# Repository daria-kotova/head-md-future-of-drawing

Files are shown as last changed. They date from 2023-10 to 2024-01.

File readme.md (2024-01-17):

This is my project with Caran d'Ache on the future of drawing, where we have to make a playful AI creative assistant. 

Current name of my assistant is Snailed-it.

Below is the devlog with my day-to-day progress. Enjoy.

# DevLog

## 2024-01-17

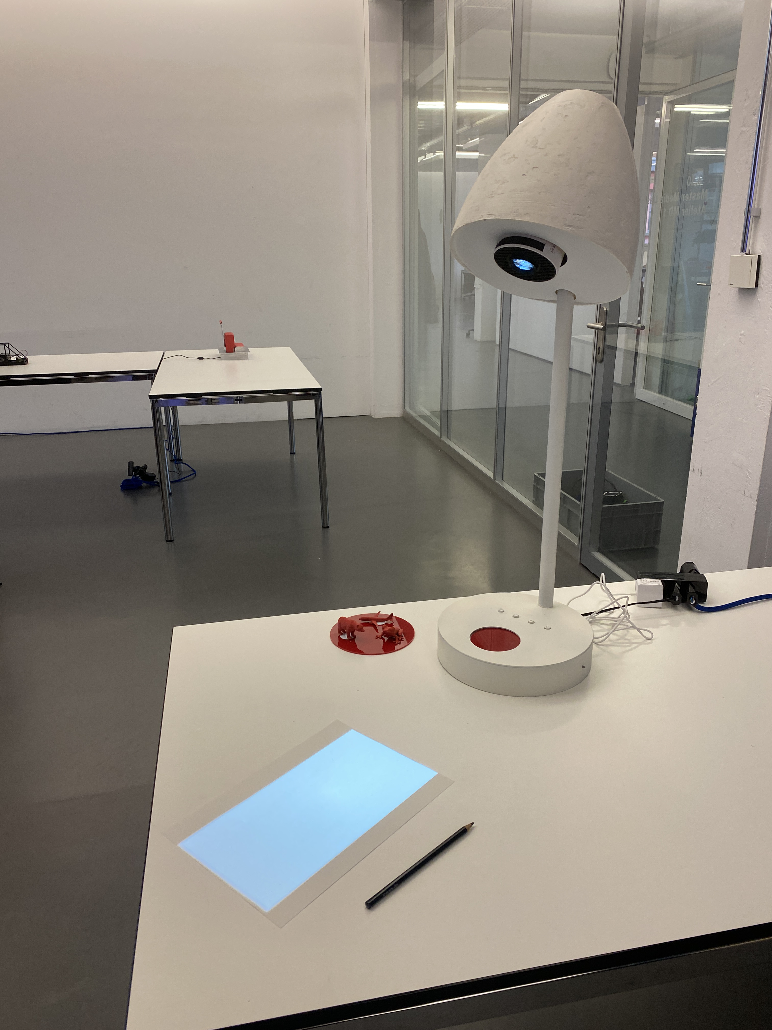
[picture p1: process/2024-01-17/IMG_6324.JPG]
exp


Murphy's law continues to work, the code that worked last night and this morning did not work during my demo. Had to show images on my iPad, again. Quite dissapointed with this, but at least I know it works and I am satisfied with the final form. Achievemebt unlocked. Product designed.

## 2024-01-16

Spent 6,5 hours figuring out my [code](/electronics/code/) with Vitas. And it worked! For now only two buttons are functional (outline and shading) and the image does not disappear when you remove an NFC tag. But still. Happy. 

However, I had not expected it to take sooo much time. So when I came back to the main building to get all my stuff, it was already locked. Had a mini panick attack. But crisis was averted, Lauren saved me.

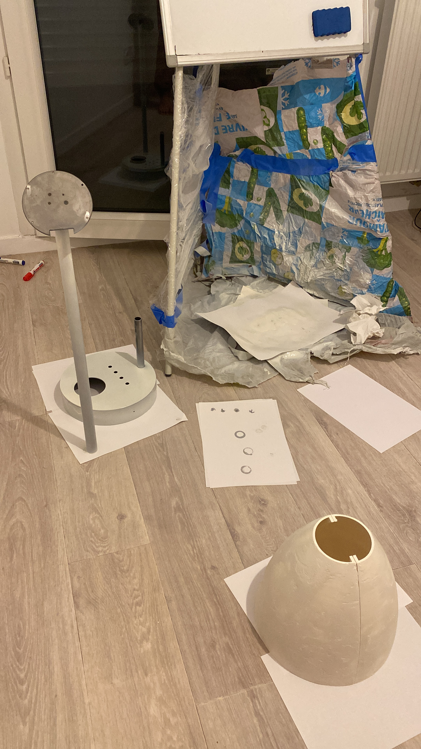
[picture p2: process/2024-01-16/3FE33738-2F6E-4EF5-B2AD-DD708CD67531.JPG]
paint
Painted my parts in white at home. 

## 2024-01-15

After some struggling with Processing I decided to code in Python, even though I had never done it before.

Tutorial for setting up RFID RC522 https://pimylifeup.com/raspberry-pi-rfid-rc522/ 

Stayed up till 1am and managed to write  scripts for reading NFC tags and displaying a related image, as well as ditacting the state of buttons. Chat GPT is trully useless in some cases, it just repeats itself and does not fix my issues.

Prepared my final [pdf](/presentations/240117_HEAD-MD1_Caran-d-Ache_Daria-Kotova-Snailed-it.pdf).

## 2024-01-14

Spent half of the day looking for a micro HDMI cable in the shops around home. It was quite a challenge, taking that it is Sunday. 

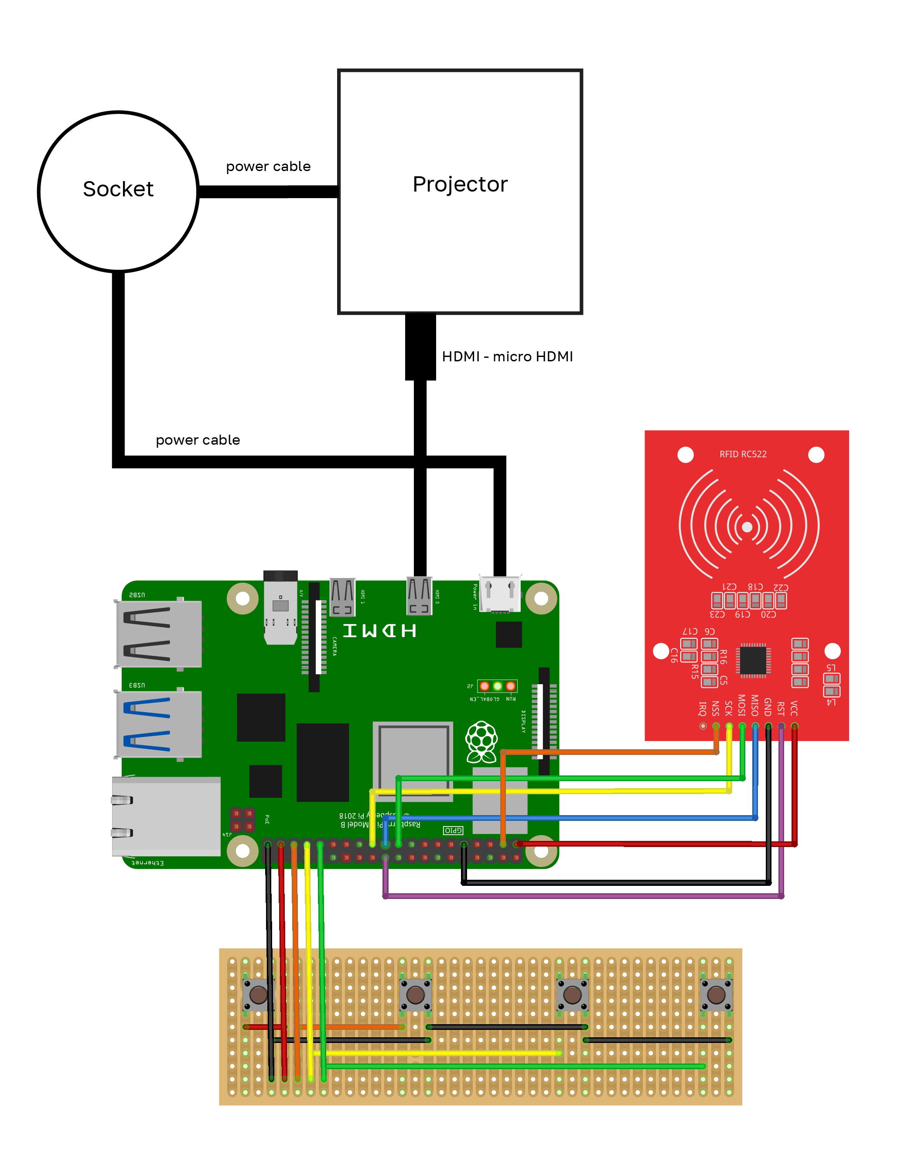
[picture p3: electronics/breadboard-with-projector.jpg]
schematic
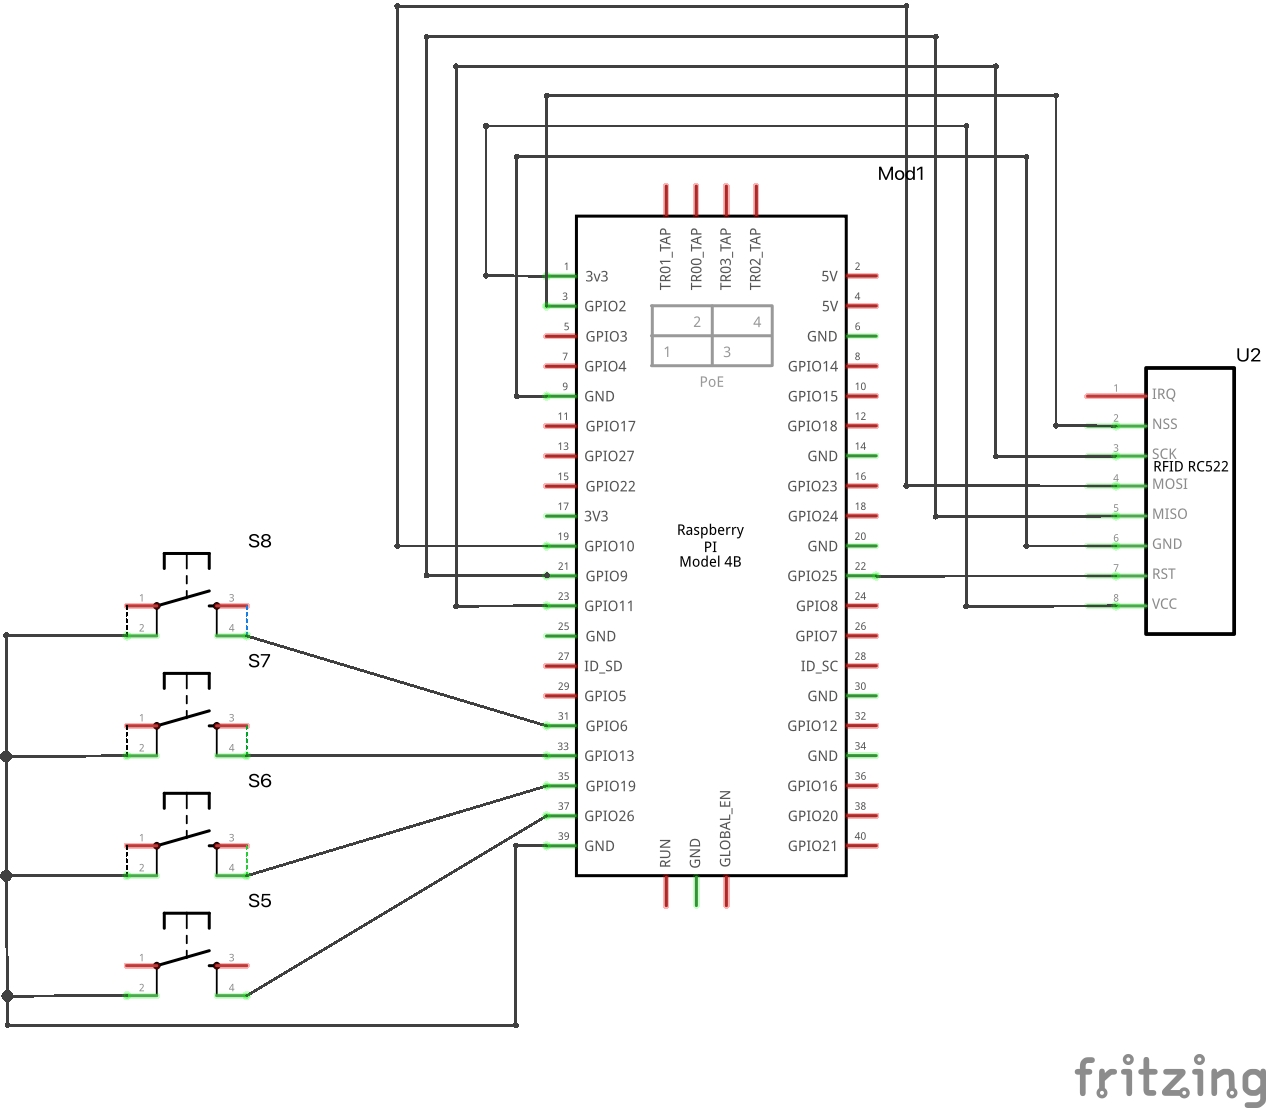
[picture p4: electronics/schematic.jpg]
shematic-1
Prepared my Fritzing schematic  

Well.. Cellotape does not really secure the SD card slot in place, the Pi keeps crushing. Will have to get another Pi from school.

## 2024-01-13

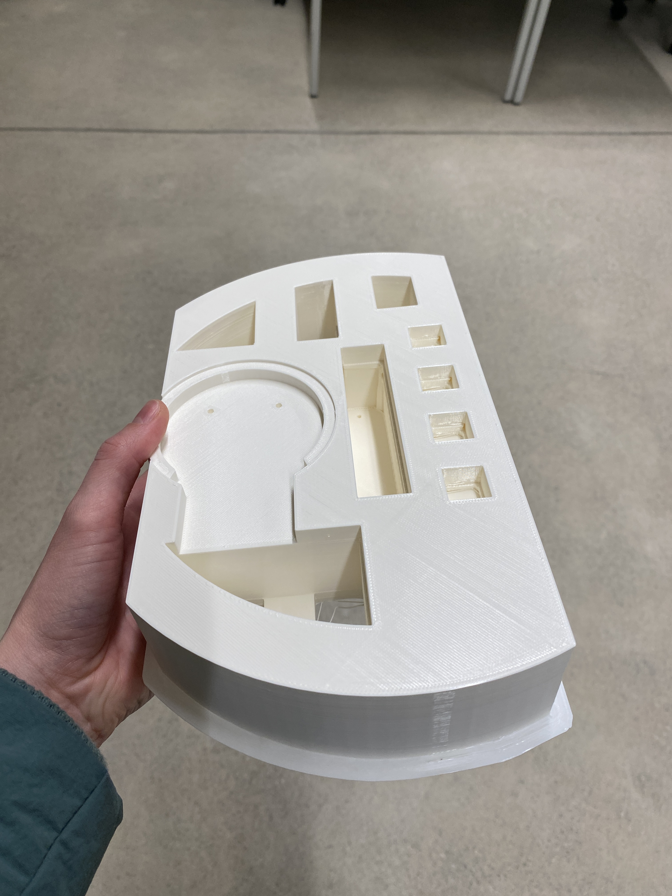
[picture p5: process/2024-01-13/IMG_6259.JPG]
base
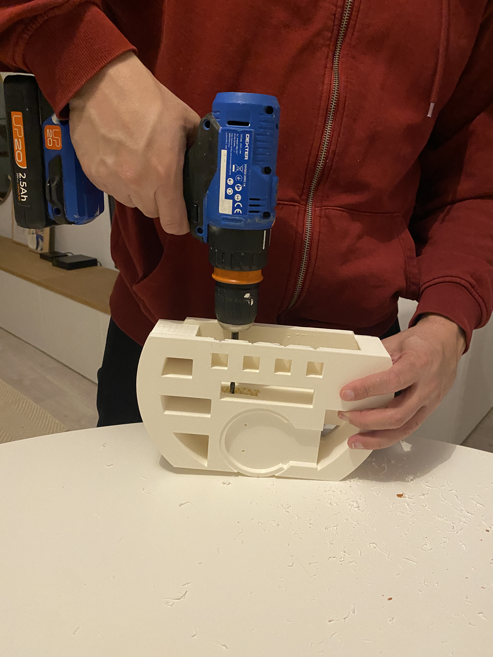
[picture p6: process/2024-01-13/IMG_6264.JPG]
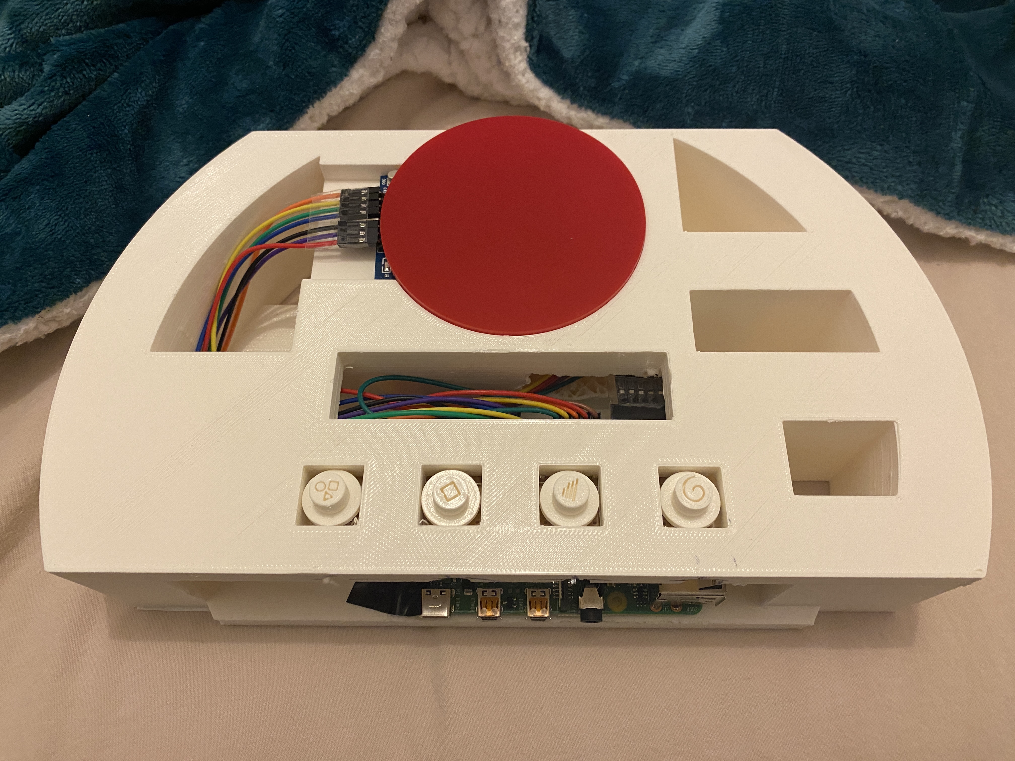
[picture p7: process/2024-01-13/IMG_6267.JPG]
Went to school to get my 3D base for electronics  Spent 2-3 hours cleaning it from all the supports, only to find out that I had made a mistake in modelling. Even two. I forgot to consider how I am going to put the strip board with buttons inside. Also, need some extra space for cables. Had to fix it with a drill.  But now everything seems to fit inside 

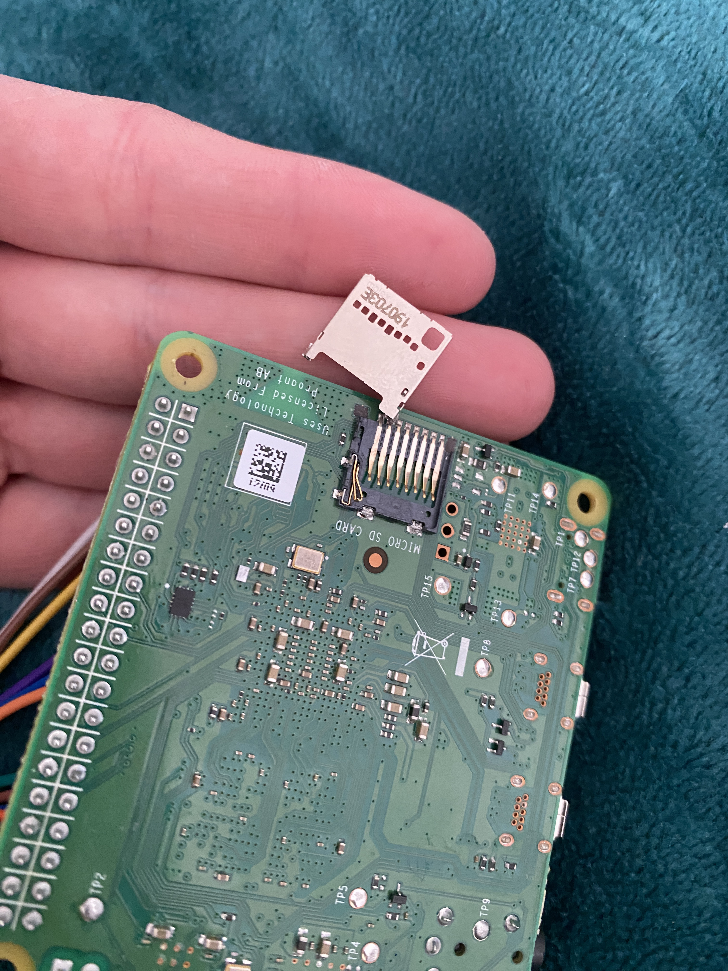
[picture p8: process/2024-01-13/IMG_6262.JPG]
slot
I somehow managed to broke the slot for SD card on my raspberry pi... 

Wanted to focus on my code, buuut... I left my micro HDMI cable at school..

## 2024-01-12

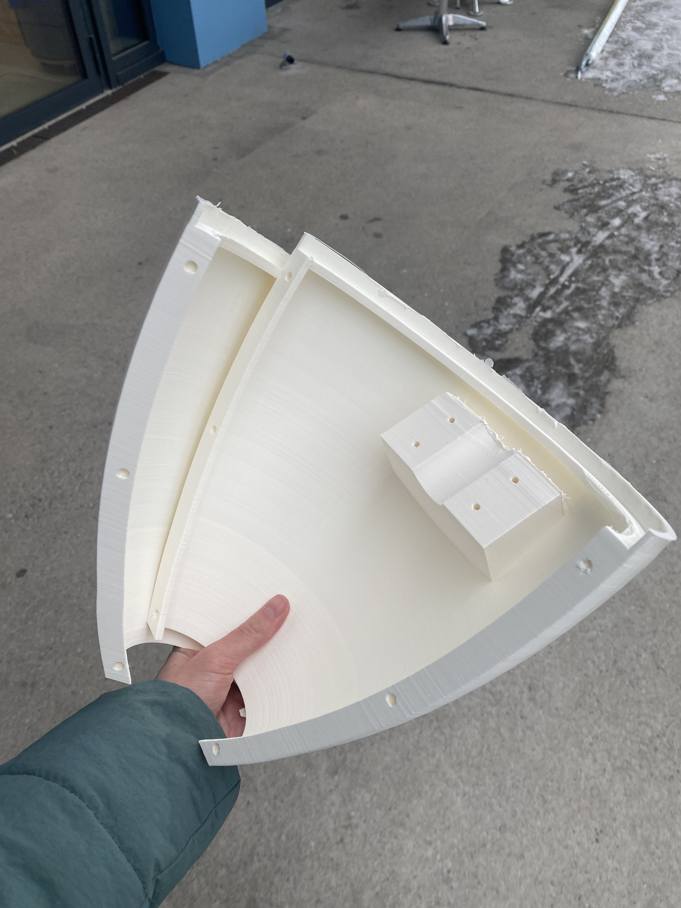
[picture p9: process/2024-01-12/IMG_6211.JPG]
parts
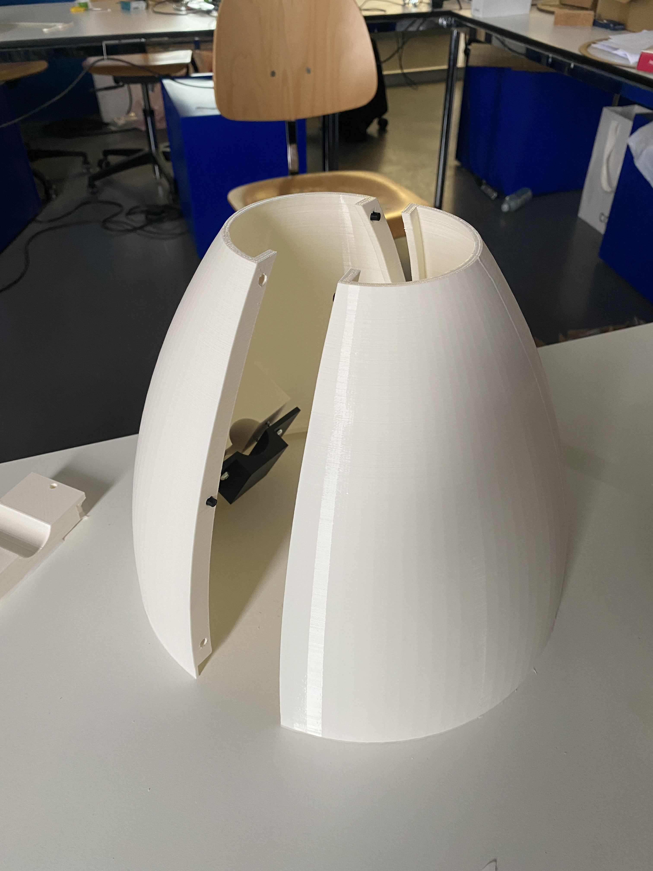
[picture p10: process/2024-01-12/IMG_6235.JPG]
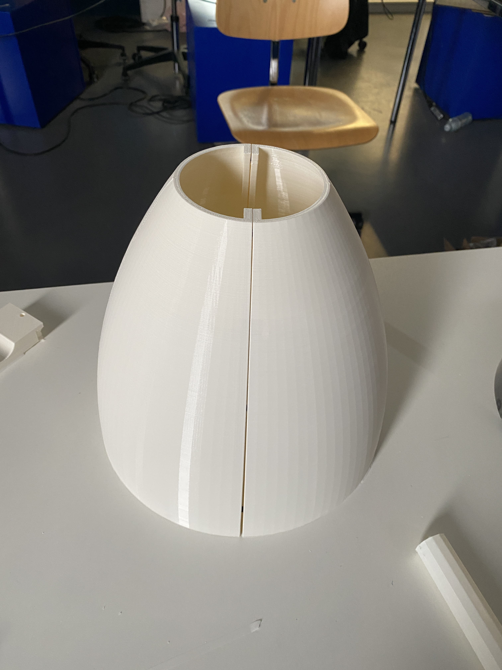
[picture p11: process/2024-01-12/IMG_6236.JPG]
Got my two big 3D printed top parts and some parts for fixations.    They took 11 and 14 hours to print. The 3D base is going to take 18 hours to print lol. The 3D printing industry needs to work more on their speed :/

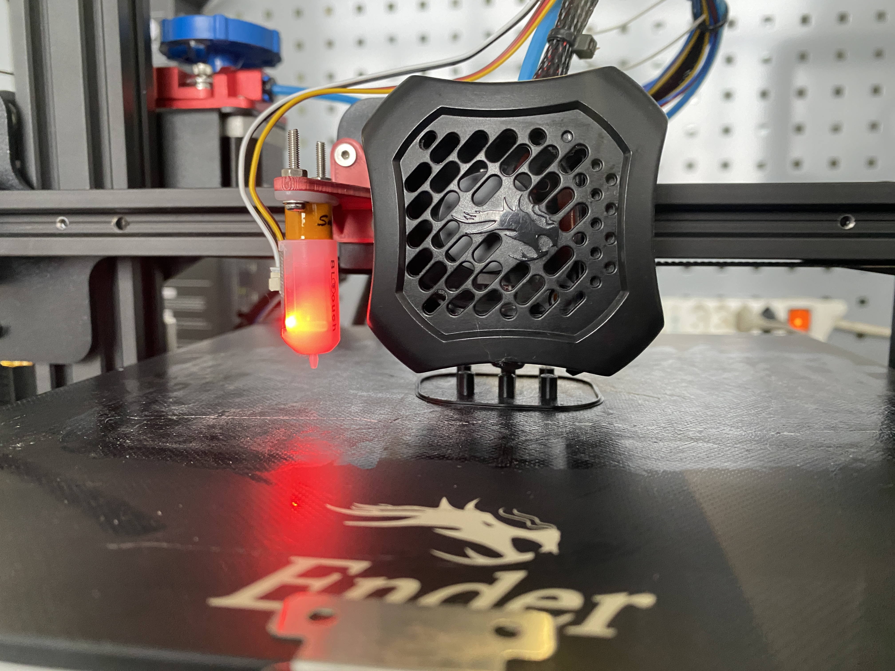
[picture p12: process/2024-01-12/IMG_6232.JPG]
The technique for connecting parts, that Fred told me about, when you make holes in both parts and then print connecting sticks separately, did not work. I completely mismatched the measurings, had to reprint the sticks twice myself 

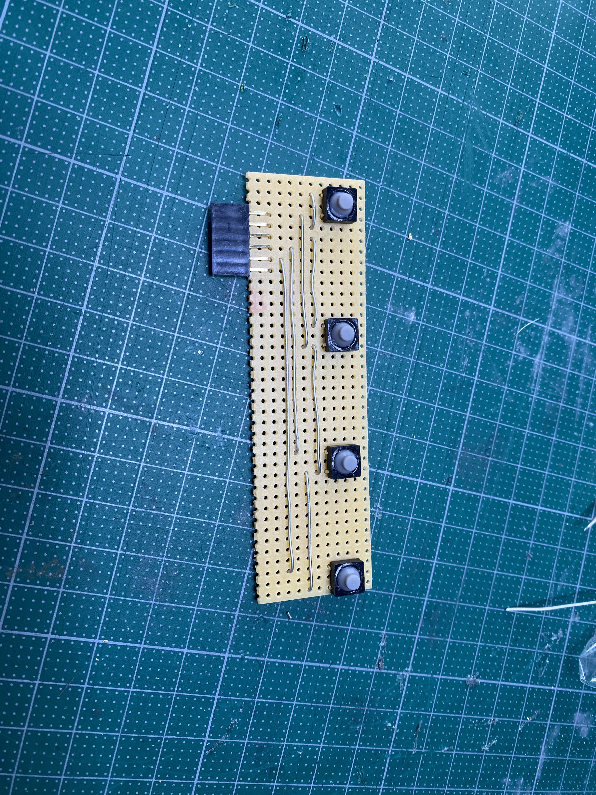
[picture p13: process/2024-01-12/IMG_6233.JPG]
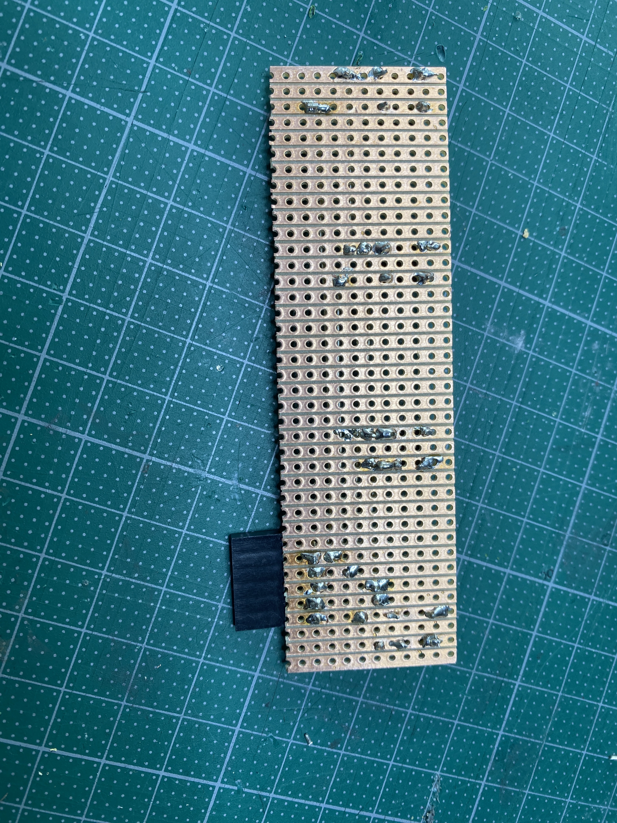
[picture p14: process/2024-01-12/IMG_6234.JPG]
Soldered my buttons. I think I am getting a hang of it.  

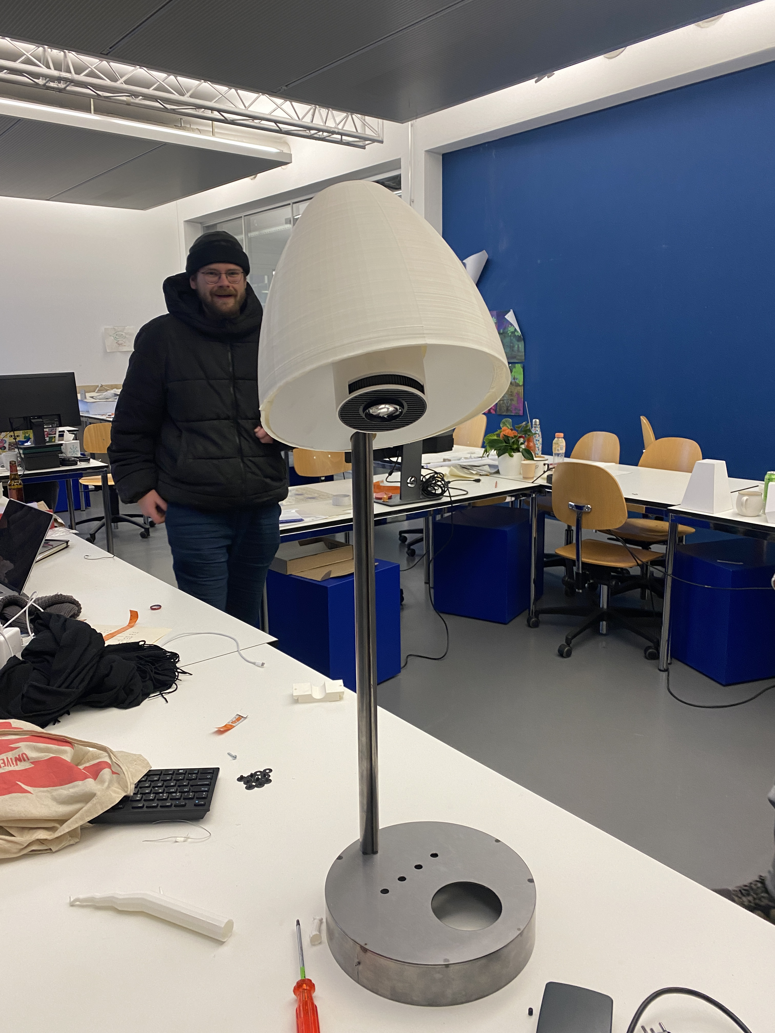
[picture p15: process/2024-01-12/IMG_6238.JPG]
form
Overall, the object is starting to take its from 

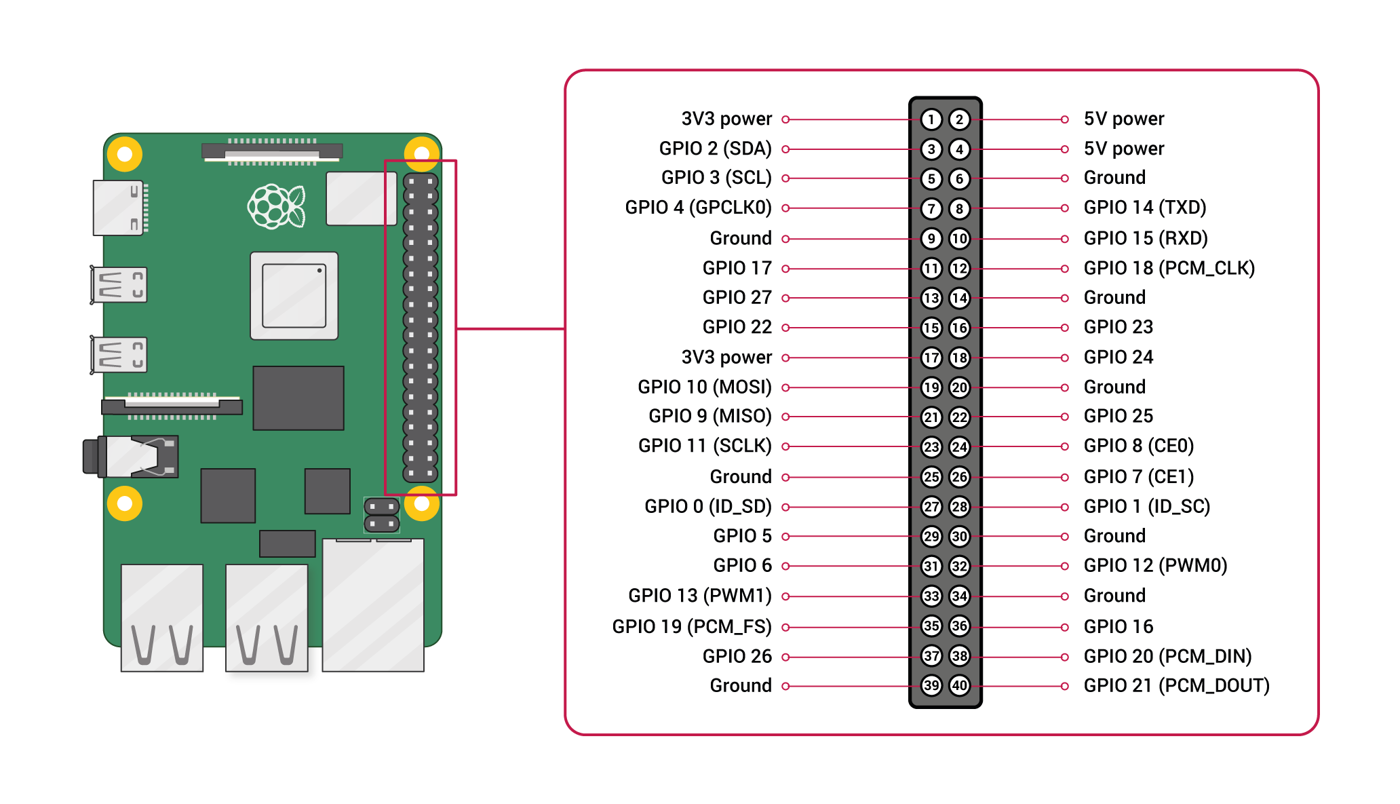
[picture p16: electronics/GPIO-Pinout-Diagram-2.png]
My Bible for the next several days 

## 2024-01-11

Got laser and zonde (?) cuts. Finally finished my battle with the 3D base. 

## 2024-01-10

Figuring out the electronics and 3D base. Prepared documents for laser cutting (fixation disks, plate, diffusor).

## 2024-01-09

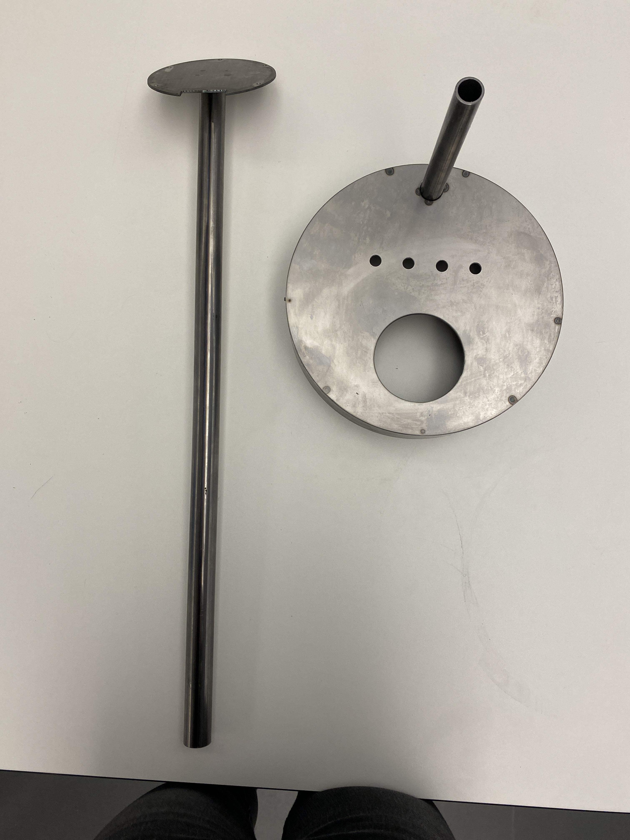
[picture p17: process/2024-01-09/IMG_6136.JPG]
metal
Went to metal workshop. We managed to finish in 3 hours. When I say we, I mean Xavier, I was just giving instructions and following him everywhere lol. Satisfied with the result.  However, at the end we realized that the tubes are to narrow and the projector power cable does not pass. Will have to cut it and get a new prise that can be opened. Ooops.

## 2024-01-08

Trying to finalize my 3D model because tomorrow I will go to the metal workshop. Still struggling a lot with the 3D base, because I fail to imagibe how everything will be positioned.

## 2024-01-10

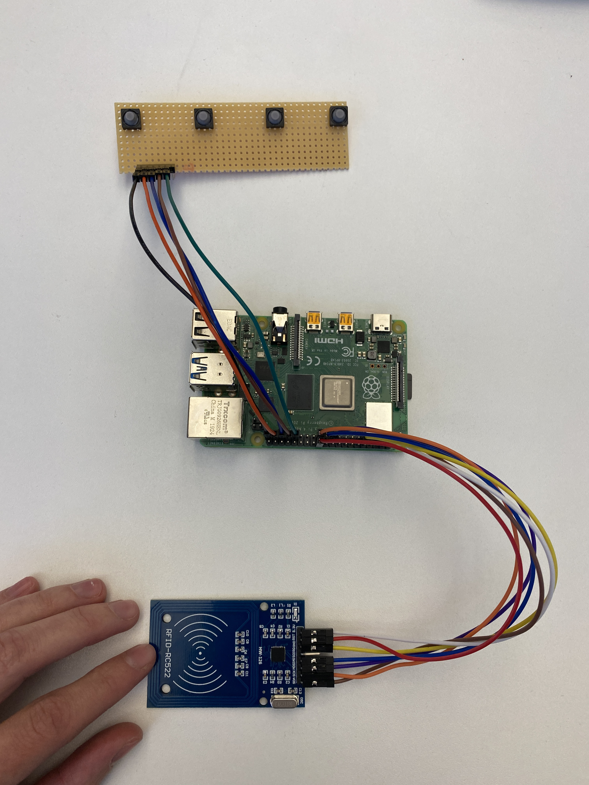
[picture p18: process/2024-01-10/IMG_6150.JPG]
solder
Finally figured out my electronics situation (how every part connects to each other). Gonna solder buttons. 

## 2024-01-04

Chose 5 more input objects (to be limited to 4). Unfortunately no snail :( Ideally, I would have modelled them myself, but seems like a waste of time with my current level of 3D modelling.

- sheep https://www.thingiverse.com/thing:182273/files
- plane https://www.thingiverse.com/thing:182252/files
- penguin https://www.thingiverse.com/thing:182246/files
- bear https://www.thingiverse.com/thing:182072/files
- frog https://www.thingiverse.com/thing:18479/files

## 2023-12-23

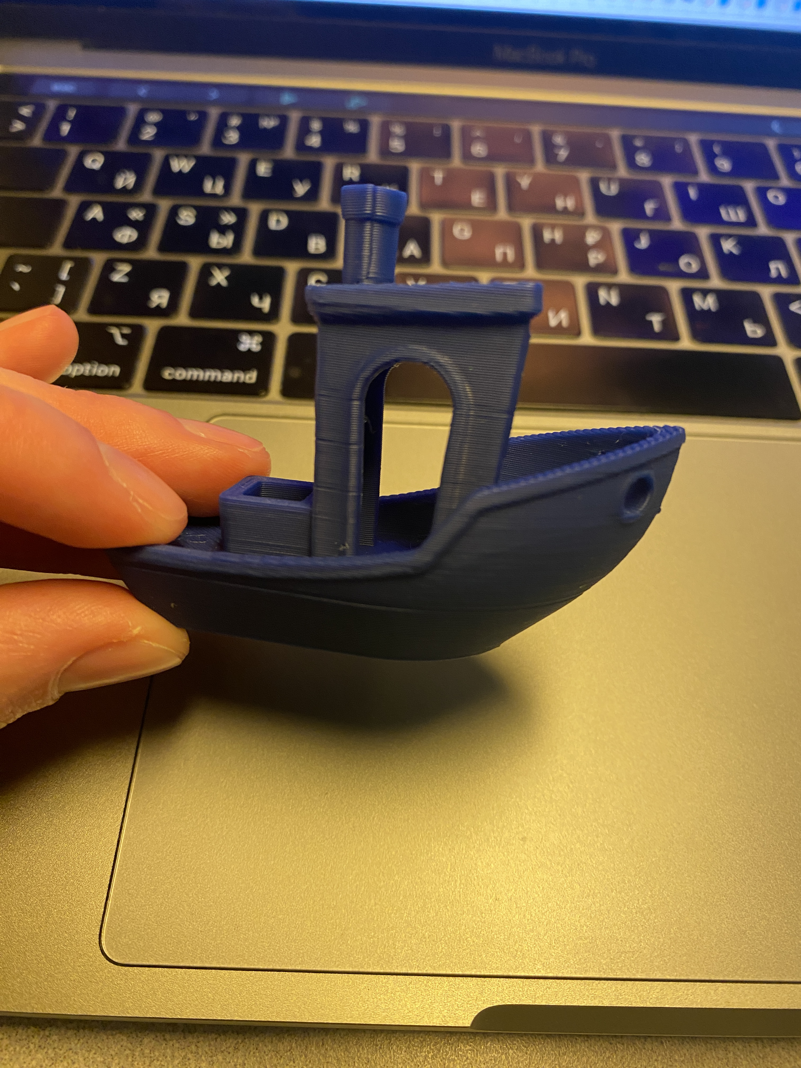
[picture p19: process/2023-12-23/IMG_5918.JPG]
boat
Jasmine got me a 3D printed boat as another input object for my project.  Now I am thinking that I should 3D print all of my input objects, so that they are all in one style. Deffinitely one of the objects will be a snail (DAH).

## 2023-12-21

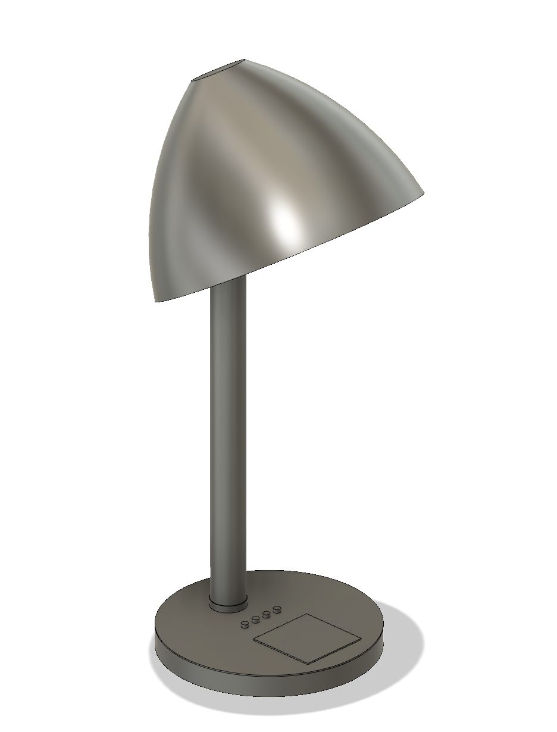
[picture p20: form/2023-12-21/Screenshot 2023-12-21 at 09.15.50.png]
shell
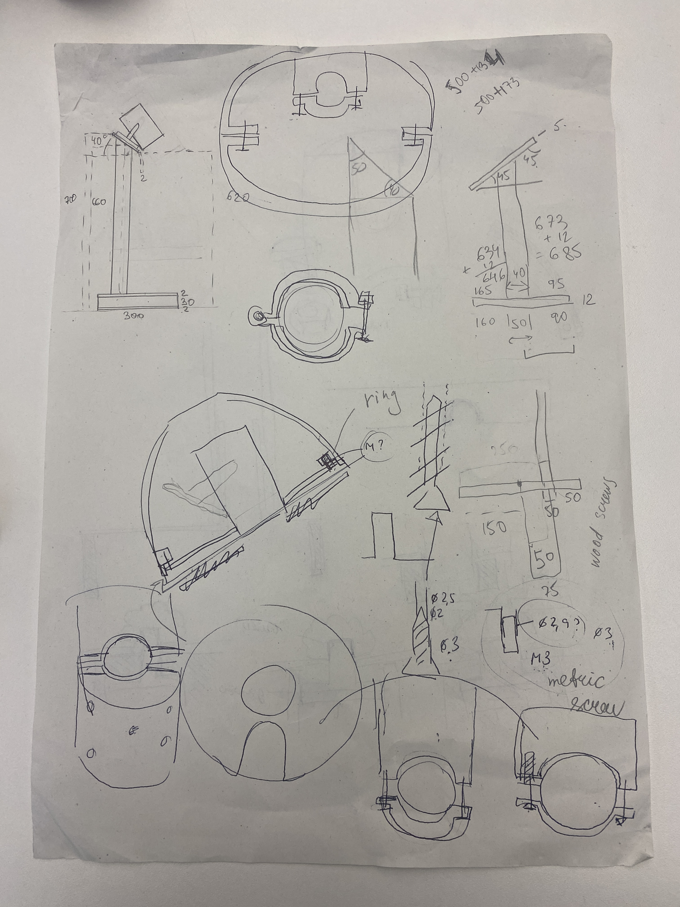
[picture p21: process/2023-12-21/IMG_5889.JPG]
clamp
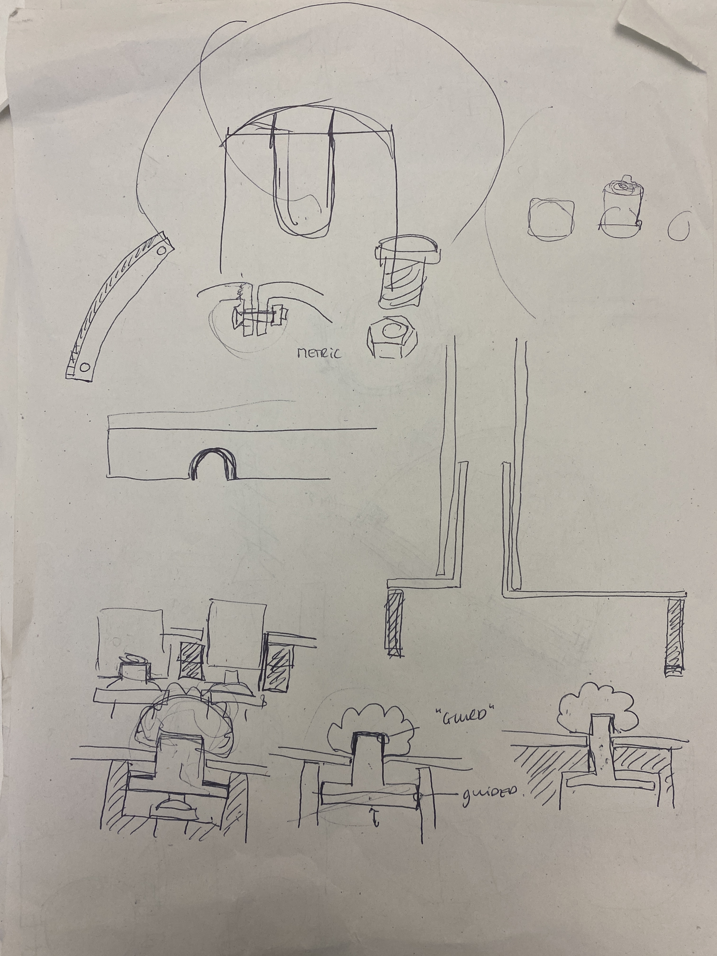
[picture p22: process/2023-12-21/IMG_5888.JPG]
Improved shape of the shell.  Now that I have the base of my model, we were able to discuss with Laure how I can fix my parts together. There will be a sort of a clamp to attach the shell to the leg  The shell itself will be printed in two parts and fixed from the inside. We also discussed how I should model the buttons 

TO REMEMBER:
- make holes for cables in the leg and in the base
- model the plate with holes that will be attached to the shell
- model buttons
- model base for electronics that will be 3D printed
- hole for camera?
- test other shapes of the shell
- invert tubes of the leg

Made an appointment at atelier de métal (Jan 9 and Jan 10 14:00-17:00). Also, just in case, booked an appointment with Chloe from pool numérique for 3D printing. But ideally would prefer print at atelier de prototypage, since they have bigger machines and a larger selection of materials.

## 2023-12-20

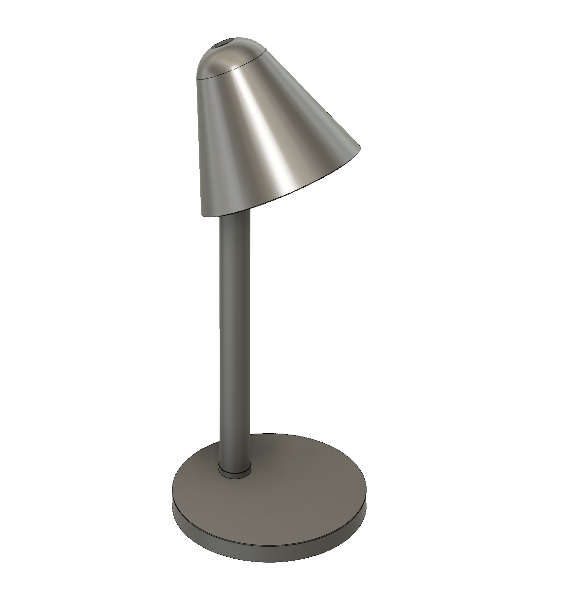
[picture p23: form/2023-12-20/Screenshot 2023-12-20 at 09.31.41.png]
model
Finally figured out how to model a project and a shell around it. 

The "random" button can be in a swirl form, to make reference to the name of the object.

## 2023-12-18

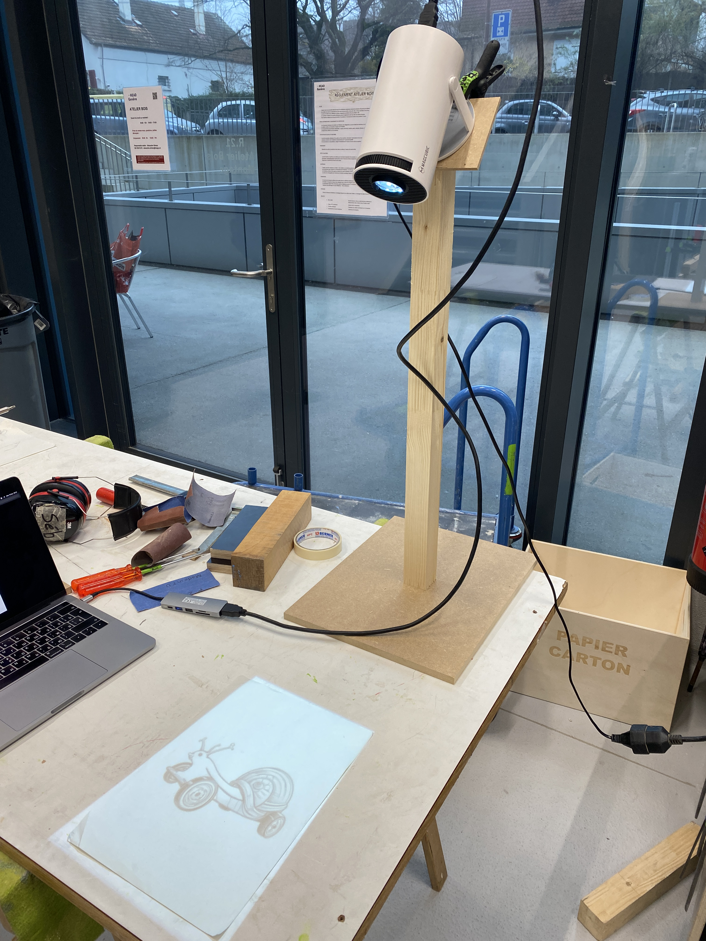
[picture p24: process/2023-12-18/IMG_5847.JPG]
baby
Went to atelier de bois in the morning. My giant baby 

## 2023-12-17

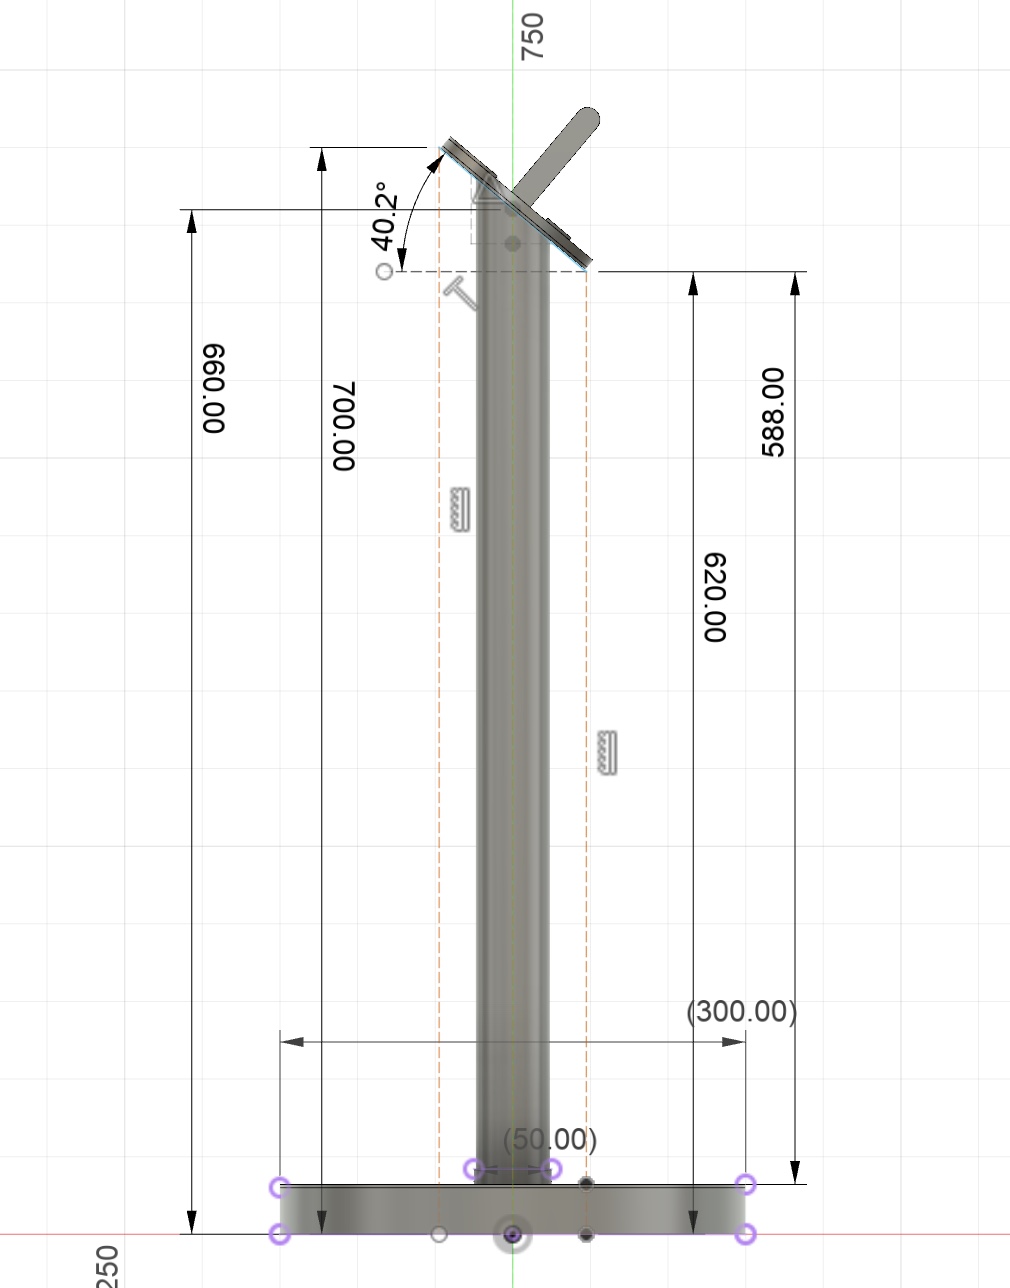
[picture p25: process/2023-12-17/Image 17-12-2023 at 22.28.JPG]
Prepared mesurements to check at atelier de bois tomorrow. Still struggling with modelling the projector :/ 

## 2023-12-14

Test day results

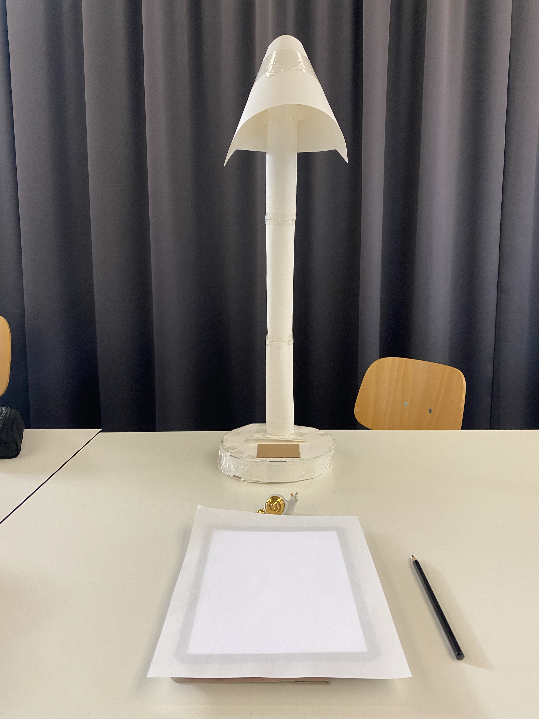
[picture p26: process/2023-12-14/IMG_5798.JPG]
test-day


1. It is still not very obvious that you need to take an object and put it on my device. In most cases I had to tell people that the snail was a part of the experience. In the second session, I tried putting it in a box right next to the device. Still unclear. Probably, having a group of objects will make things clearer. In addition, I need to try putting objects on some kind of a platform made of the same material as the square for positioning objects on the device.

2. The device is perceived as a lamp. Still need to think if that is the impression I want.

3. Blank buttons were not clear at all. Only one tester was curious enough to explore them without any explanation. Buttons with icons made more sense. Even though the icons were not always very understandable, they at least sparked some interest. Buttons with text are probably too in the face, but at the same time still not super clear. Will probably keep buttons with icons, but will reconsider the icons.

4. An interesting insight is that the first three buttons (outline, shapes, shading) are associated together. Some people saw them as different layers of one image. Meanwhile, the random button is a very fun option, but is a bit apart. So, the idea now is to group the three first buttons together and distinguish "random" from them (by color or shape and distance, like a golden button with a dimond on top, and encourages people to press it first). Also, need to switch positions of "outline" and "shapes" because it is more logical the other way round if we consider the drawing process (shapes -> outline -> shading).

5. When clicking on the random button again, people expect a new random image.

6. What if you put two objects? Does the assistant mix them?

7. "Shading" -> "volume"? "details"?

For the head part can use plastic instead of 3D printing.

Agreed with the guy from atelier de bois that I would come on Monday morning to verify my mesurements with wooden planks.

## 2023-12-13

Was preparing for test day.

Objectives:
- Test if people understand that this is a device that can recognize an object and then project it
- Test if people can understand each parameter without icons or text on the buttons
- Test if text descriptions are clear enough.

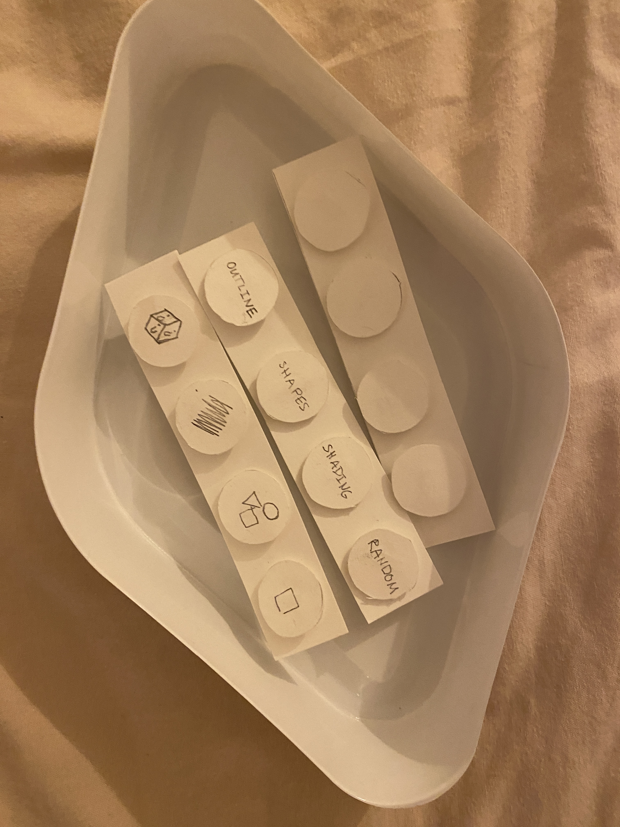
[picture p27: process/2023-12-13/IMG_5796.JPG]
Made a new paper prototype that is close to the original size. Also prepared three sets of buttons 

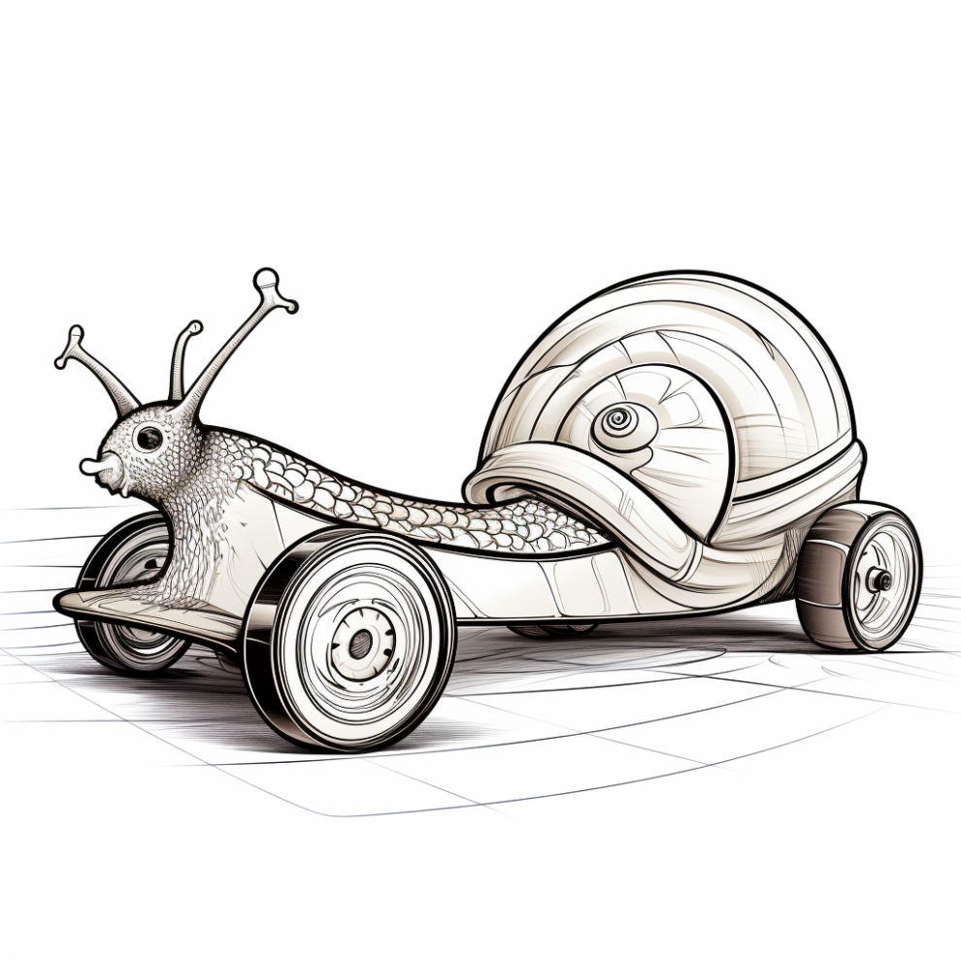
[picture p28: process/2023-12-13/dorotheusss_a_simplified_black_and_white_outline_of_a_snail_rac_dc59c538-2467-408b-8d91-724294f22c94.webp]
racing-snail
After talking to Lauren added a new option of getting a projection of shading. Also, decided to get rid of the potentiometer and replace it with just a "random" button for unexpected interpretations of the object by AI. Played more with Midjourney. This is a racing snail 

## 2023-12-12

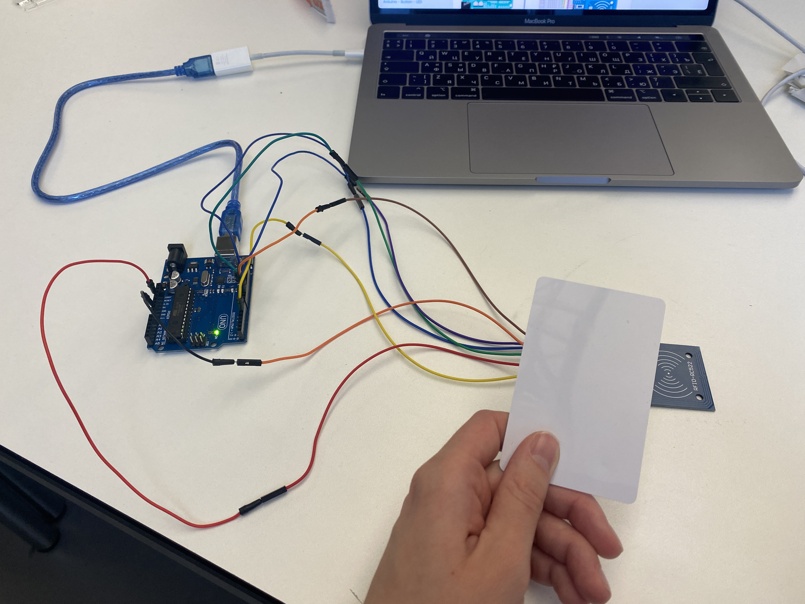
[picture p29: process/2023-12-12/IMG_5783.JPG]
RFID
Tested RFID reader again.  The maximum distance between it and an NFC tag is around 3cm, 1cm from each edge of the reader.

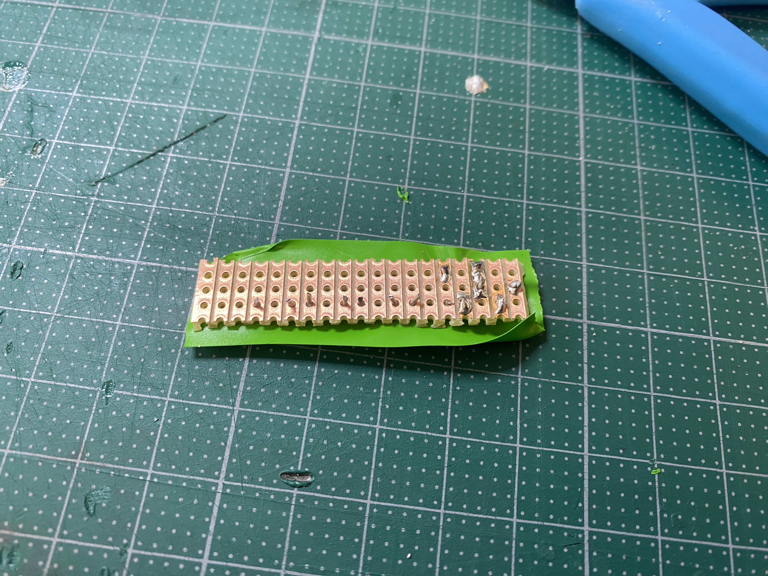
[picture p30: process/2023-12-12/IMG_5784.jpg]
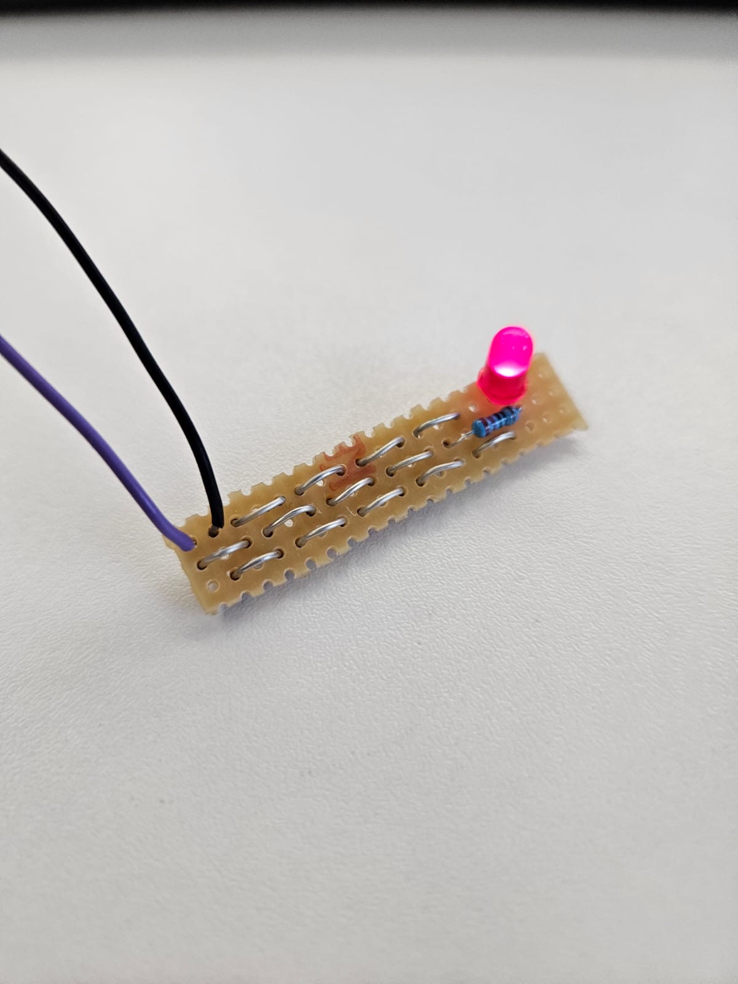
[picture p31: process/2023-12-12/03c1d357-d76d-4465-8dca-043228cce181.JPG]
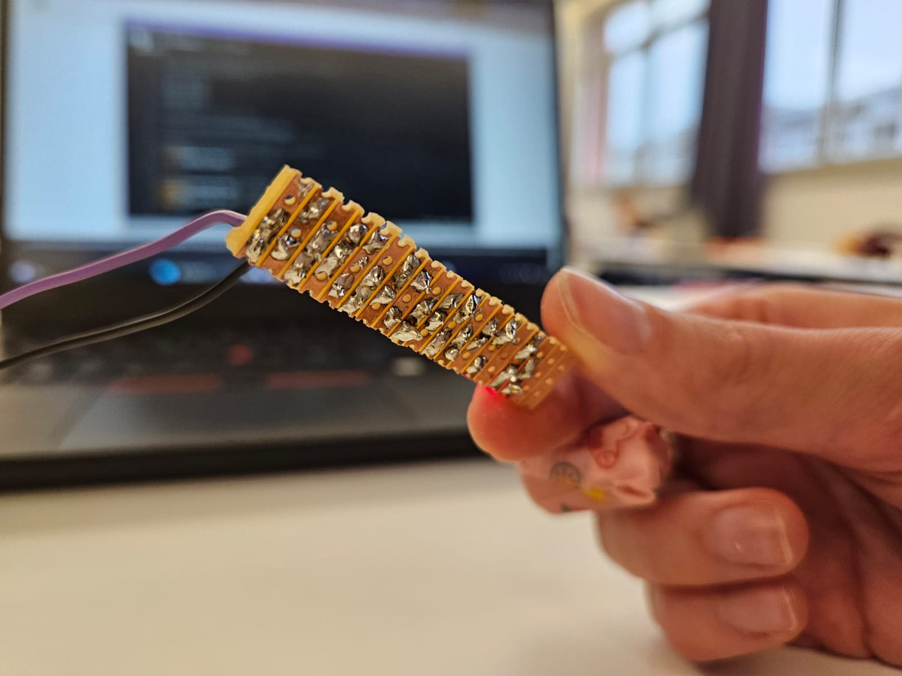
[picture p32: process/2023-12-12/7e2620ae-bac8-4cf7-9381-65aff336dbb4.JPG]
Did a soldering exercise. It was very difficult because my hand was shaking af, but at least it worked from the first time.   

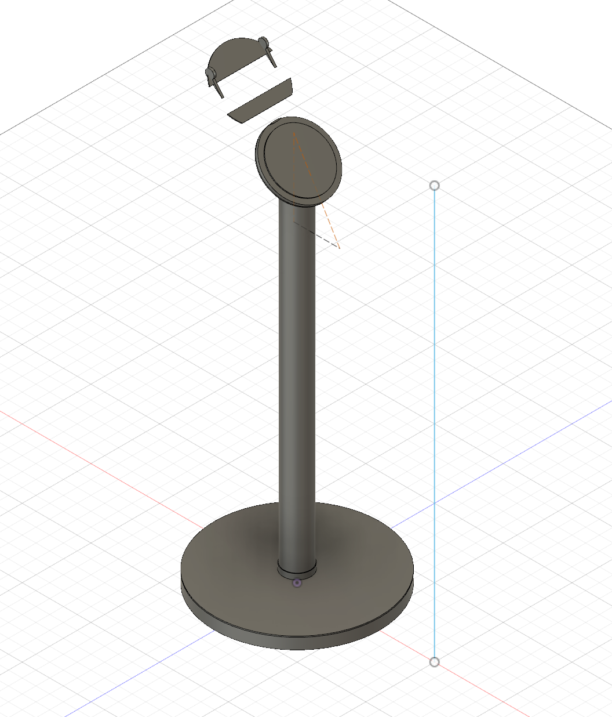
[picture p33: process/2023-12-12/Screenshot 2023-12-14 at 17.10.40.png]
3D
Current state of my 3D model.  Struggling with adding the projector.

## 2023-12-11

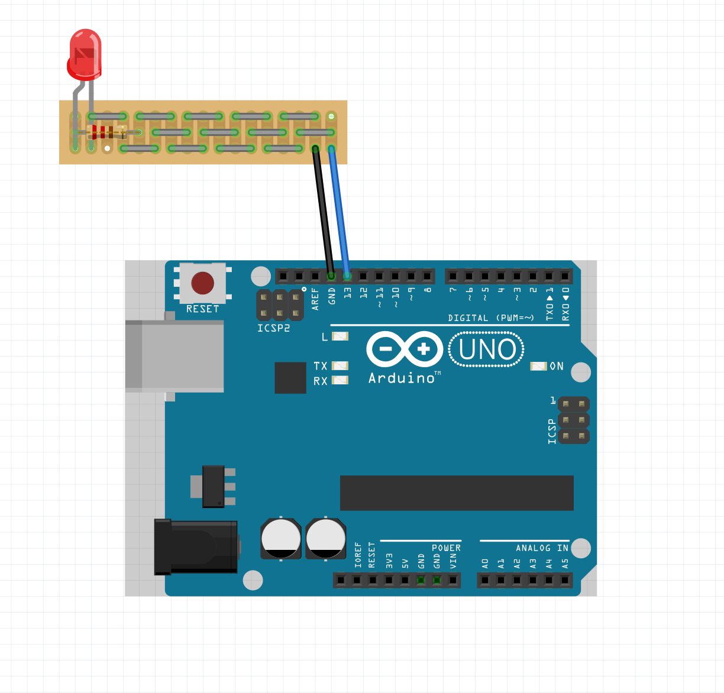
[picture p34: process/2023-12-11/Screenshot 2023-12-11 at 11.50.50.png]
Learnt how to use Fritzing. 

Turns out the reader did not work because I needed to secure connection by soldering a part to it. Pierre soldered it for me. To be tested again.

## 2023-12-09

Tried testing RFID reader. It kind of works if I connect all the cables directly, but this configuration is very unstable. Otherwise, I get an error.

## 2023-12-07

Need to think about the way I can cover power cables, because there will be one from the projector and one from the Raspberry Pi. Probably can put them in some textile with velcro.

Added necessary [steps](/process/2023-12-07/steps.md) for completing the project.

Talked to the guy from the Metal Pool. They have all sorts of steel tubes and plates, so basically it is up to me to decide on the size and thickness. Will need to finish my 3D model BEFORE THE HOLIDAYS, so that he can order necessary materials if needed. And straight after the holidays we will start production (Jan 8). The gravure of the text for my parameters can be made at the Prototype Pool.

His suggestion on how to do the base and fix the leg to it:
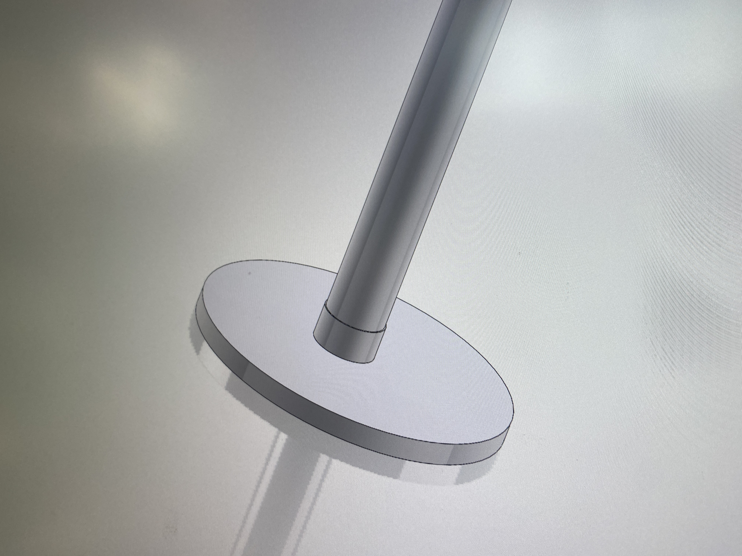
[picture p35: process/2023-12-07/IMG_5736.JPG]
suggestion_1

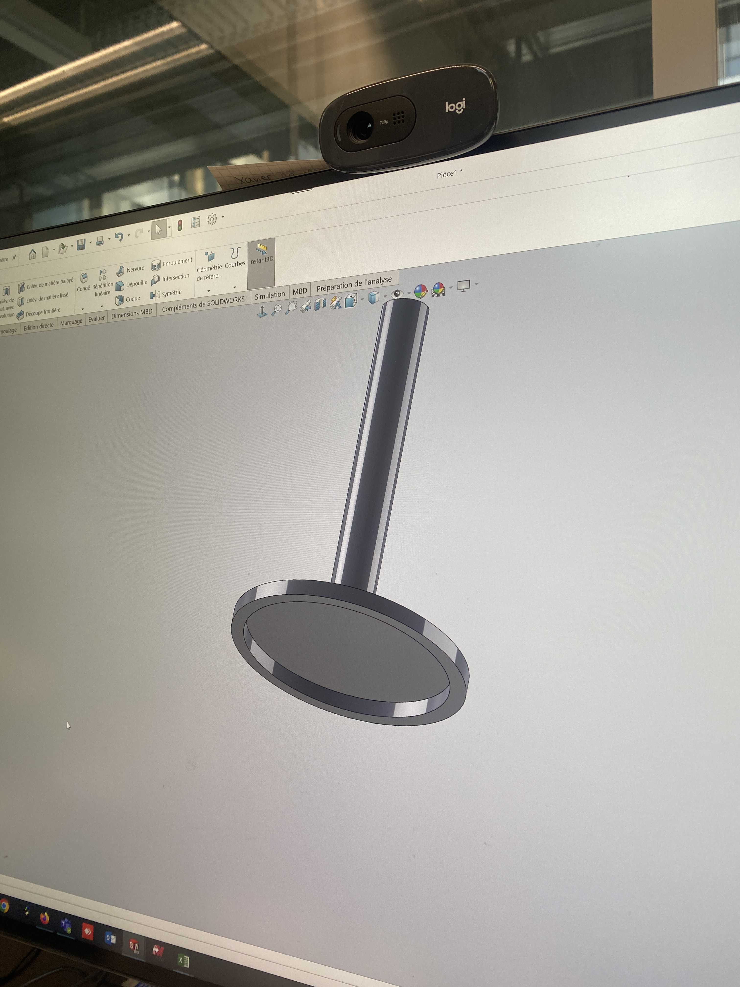
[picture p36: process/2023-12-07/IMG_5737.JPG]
suggestion_2

There will be a short large tube soldered to the base and the main tube will go inside and will be fixed with screws/bolts. The base is hollow, so that I can fit my electronics in it.

Need to think if I actually want to make a wooden prototype first. Probably only for some details. 

## 2023-12-06

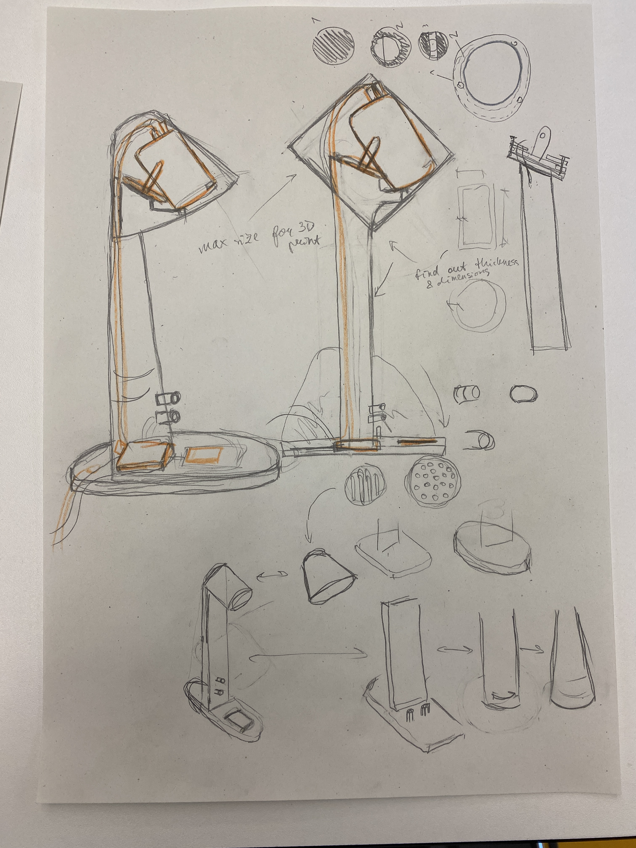
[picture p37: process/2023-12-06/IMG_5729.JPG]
sketch
Made first detailed sketch of my object. 

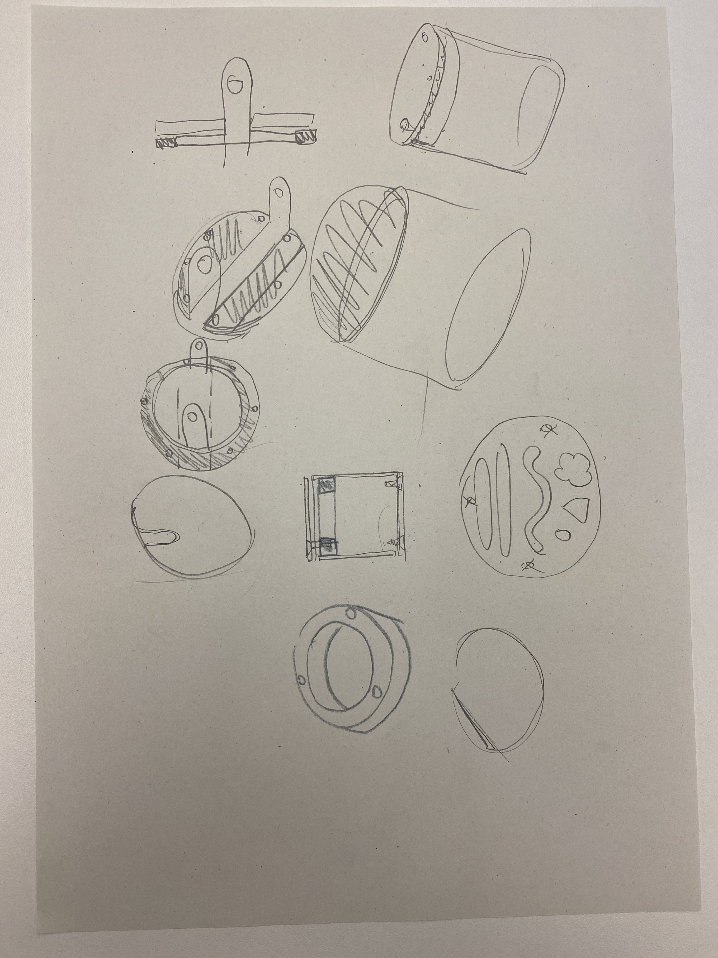
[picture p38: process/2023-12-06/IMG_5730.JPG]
disks
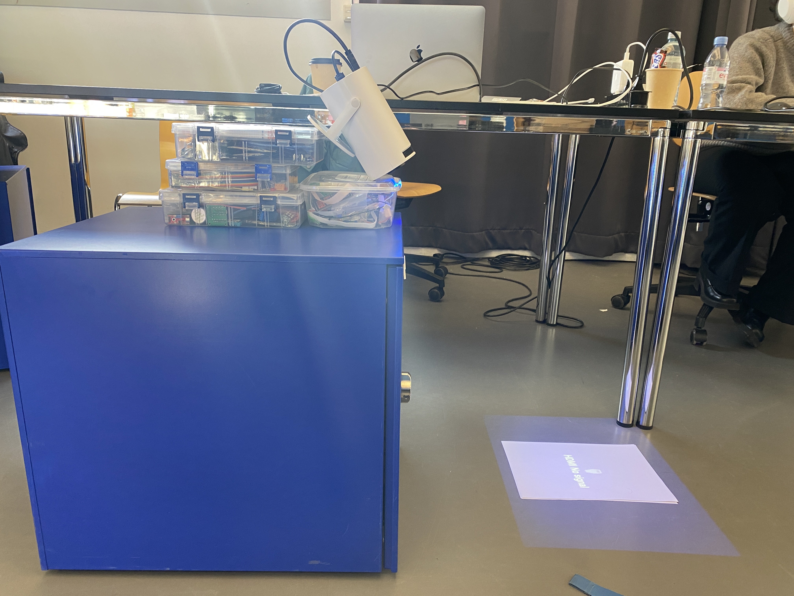
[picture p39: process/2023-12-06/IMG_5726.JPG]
construction
Since the projector is quite heavy (820g), the leg and the base should be metal, so that the object does not fall. The projector will be attached to the leg with three disks and a bolt.  The shell of the head will be 3D printed, since it will allow to have a light top, probably with two parts. One part with holes for ventilation, because the projector heats up easily. Unfortunately, the object will have to be taller than I wanted (around 700mm), so that the projection is not too blurry. 

Got a Raspberry Pi, SD card and cables from Pablo.

## 2023-12-05

Chose my electronic components:

- [RFID](https://www.distrelec.ch/fr/module-de-lecture-et-ecriture-rfid-compatible-arduino-13-56mhz-velleman-wpi405/p/30260977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) reader
- [NFC](https://www.adafruit.com/product/360) tags
- [Raspberry](https://www.adafruit.com/product/4292) Pi 4 Model B - 2 GB RAM 
- 3 soft [buttons](https://www.adafruit.com/product/3101)
- potentiometer with a metal [knob](https://www.adafruit.com/product/2058)
- projector (ideally Pico projector because it is small and light, but for now I have [this](https://www.amazon.com/Projector-Magcubic-Keystone-Correction-Portable/dp/B0C84JLZ9K?th=1) )
- [camera](https://www.adafruit.com/product/5657) (in a perfect world)

## 2023-12-04

Talked to Pierre and Laure. For the simplicity, it makes sense to use an NFC reader instead of a camera for object detection, as well as predetermined objects with NFC tags. Otherwise, it is going to take ages to teach the AI to recognize random objects.

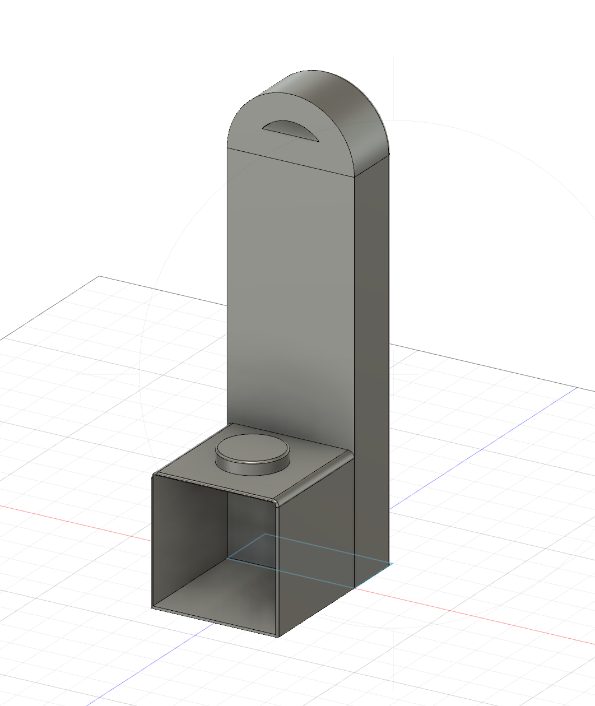
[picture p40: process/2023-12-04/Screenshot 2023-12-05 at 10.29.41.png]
3d_sketch
Tried to make a quick 3D sketch in Fusion  Kinda looks like a tomb stone..

Discussed possible shapes with Laure. Since, I am going to use NFC tags, I do not really need to make a box for putting objects. It can be just a flat surface. shape In any case, the shape will be largely determined by my electronic components. Need to think about materials.

## 2023-12-01

Tried RGB LED light RGB_LED_1 RGB_LED_2 RGB_LED_3

## 2023-11-30

Started learning Fusion. It is actually not that difficult, much easier than Blender and Cinema 4D. Made a pencil sharpener model sharpener_1 sharpener_2

## 2023-11-29

More electronics. Learnt how to use PIEZO piezo

Experimented with a light sensor light_sensor_1 light_sensor_2 and with a servo motor servo

## 2023-11-28

Now I know how to use a potentiometer and buttons. For buttons there is an internal resistor, that should be turned on via the code. This simplifies things. 

## 2023-11-27

Started learning electronics and how to use Arduino. Made SOS in Morse code with an LED.

## 2023-11-25

Added electronics scheme scheme

## 2023-11-16

Had mid [presentation](/presentations/HEAD-MD1_Caran-d-Ache_Daria-Kotova_Snailed-it.pdf) with Caran d'Ache.

Feeling awesome afterwards. On Monday morning I felt very frustrated and anxious, because I did not know if my idea made sense and was doable. But after several feedbacks on Monday, Wednesday and today, I feel quite reassured and somewhat relieved. I am also happy to finally understand what exactly I want to do. My project now has a mystery aspect, which I wanted to introduce but did not know how.

I sensed some excitement from Laure whenever she started asking if you can put my object on the table or on the floor or wherever. Do not know if Sophie liked it, she asked some clarifying question about the learning aspect, but I guess that is the topic that interests her in general.

Insights from this week: I need to plan wisely and the most important one is that I should ask for some feedback before judging myself (dah).

No idea how to start the electronics and how to improve my prototype but I will just trust the process and go with the flow. Peace.

## 2023-11-15

Finished slides for mid-presentation. Changed the name of the project to Snailed-it. Snailed-it because you nailed it :) but also because of the snail snail

Also did some [user tests](/process/2023-11-15/user-tests/) for my last prototype, generated [Midjourney](/process/2023-11-15/midjourney/) illustrations to show the possible weirdness of AI's interpretations, as well as created various projection [outputs](/process/2023-11-15/output/).

## 2023-11-14

Today I made a new paper prototype based on Laure's feedback. It kinda looks like a phone-scuba-diving thiny. prototype

## 2023-11-13

Cried a bit in the toilet. Am I even a designer? What a beginning to the week.

[Tested](/process/2023-11-13/user-tests/) Kick-starter. Apparently, having an assistant that you need to wake up is not obvious and very confusing. Abandonned this idea. Also, need to make it OBVIOUS that you need to put an object somewhere.

Had feedback from Laure, really helped and lifted up my spirit. Why does the assistant have to draw the outline for you if it can just project it. Genius. Can also have several options, like outline, decompose, magic (to add more stuff) and random (to randomize the output and add some spice). Feeling much better. Maybe I am a designer.

## 2023-11-12

**Pitch (what, who, where, and how), first version.**

Kick-starter is an assistant that helps people start drawing using the outlines of small objects around them. It is designed for people looking to occupy their free time. These people are open to drawing but do not know where or how to start. Kick-starter can be used at home, in the office or even at school. Simply place it on a sheet of paper and choose a small object to use as the basis for your future drawing. After analysing your object, Kick-starter draws its outline, which you can then use to kick-start your drawing.

**User journey**

kick-starter-user-journey

**Key insights**
1. There is existential boredom, when people have suddenly a lot of free time and they are looking for ways to occupy themselves.
2. A lot of people do not mind drawing but they do not know what to draw and how to start.
3. Some people feel bored when they are alone. Drawing in a collaboration can be more fun.

**Next steps**

## 2023-11-11

Made a paper prototype of [Kick-starter](/process/2023-11-11/kick-starter) - an assistant that allows you to draw the outlines of small objects and thus start a drawing.

kick-starter-1

## 2023-11-07

Prototype idea: the assistant detects if you put something on the paper, it then immediately rushes to the object and starts drawing around it. Drawing with negative space.

negative_space_1 negative_space_2 

## 2023-11-03

Why do I focus on textures? My assistant could help to draw whatever you want. You put something inside it, choose what outcome you want (complexity) and it scans the object and then draws it based on your settings. Thus it invites you to explore the world around you and helps you to overcome the initial creative block ("I do not mind drawing but I do not know what to draw and how").

prototype_3

It can say: "Show me the world and I will show you how to draw it", "I want to learn more!.

## 2023-11-01

Continued doing [texture](/process/2023-11-01/textures-new-tests) and [sound](/process/2023-11-01/sound-tests) tests. Decided not to persue with [tastes](/process/2023-11-01/taste-tests) and sounds.

Made two prototypes: [texture-to-brush hand](/process/2023-11-01/texture-to-brush-hand) texture-to-brush hand and [texture-to-image convertor](/process/2023-11-01/texture-to-image-convertor).

texture-to-image convertor

Need to think on how to add the mystery/exploration aspect to the assistant.

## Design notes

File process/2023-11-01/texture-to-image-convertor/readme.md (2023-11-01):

# Texture-to-image convertor

## Description

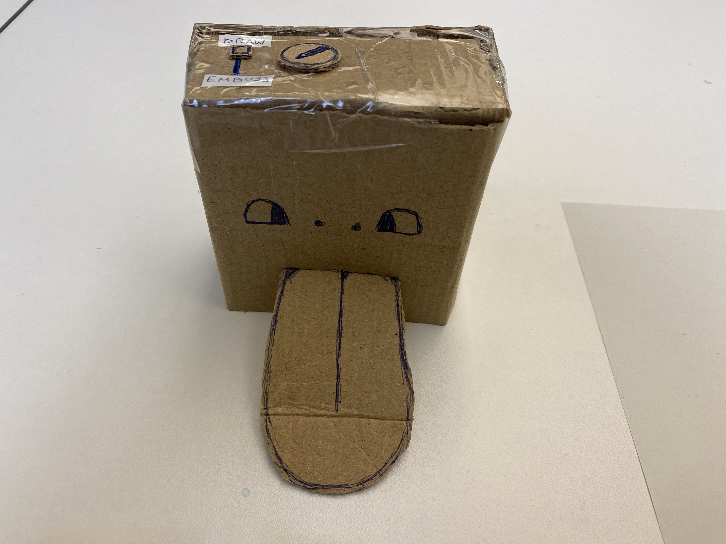
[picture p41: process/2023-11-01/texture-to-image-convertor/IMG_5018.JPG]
texture-to-image_1
 This device is an AI that is capable of producing abstract drawings from textures. 

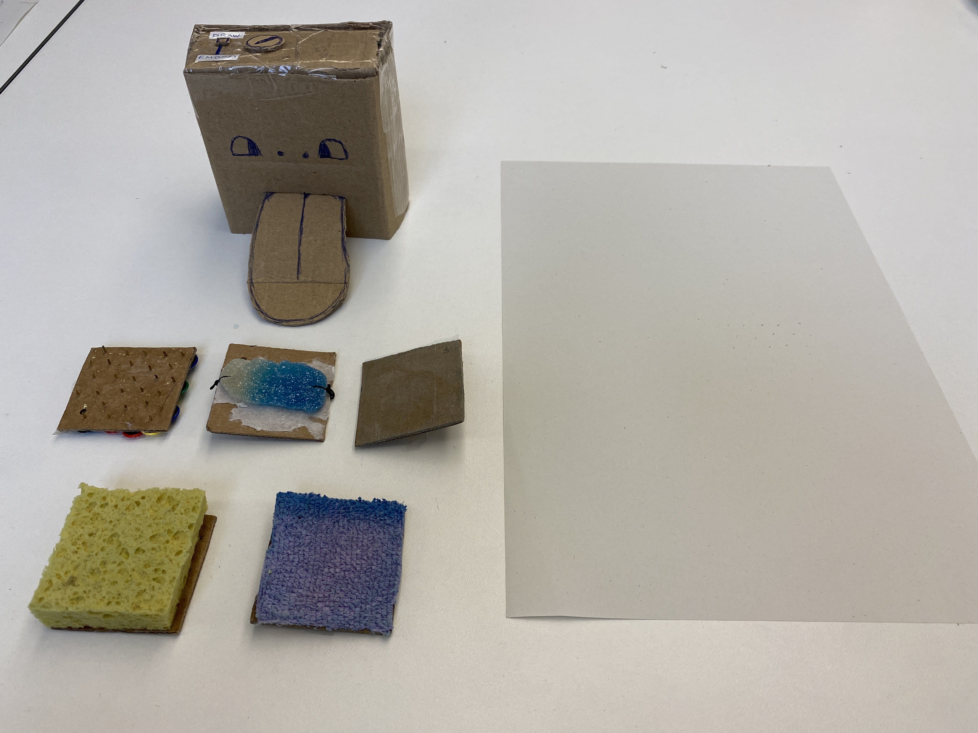
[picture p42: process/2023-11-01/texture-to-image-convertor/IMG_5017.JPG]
texture-to-image_1


The tongue has sensors to detect and analyse any texture. After placing your texture on the tongue you can choose if you want to have a simple drawing or a drawing with embossement.

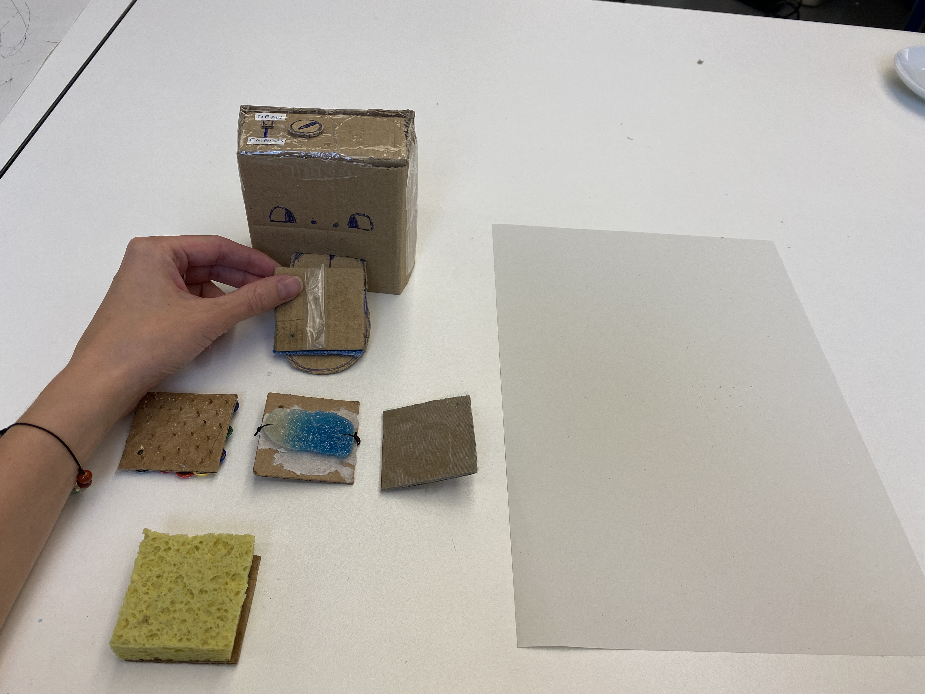
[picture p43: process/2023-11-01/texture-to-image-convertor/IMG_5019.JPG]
texture-to-image_1


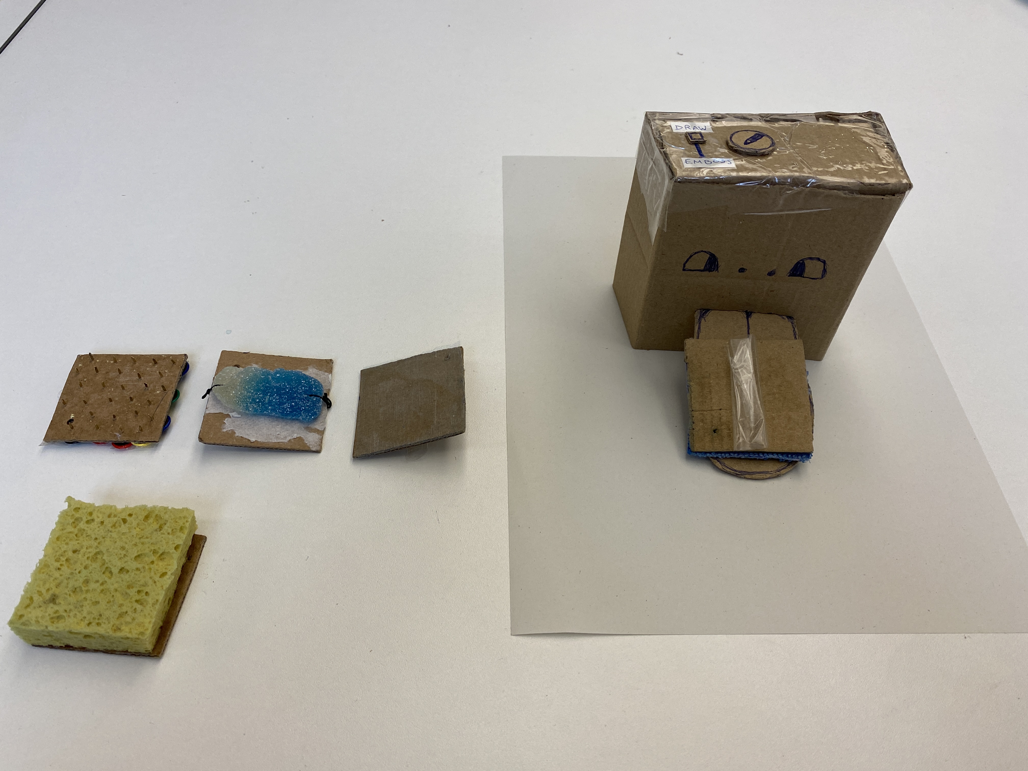
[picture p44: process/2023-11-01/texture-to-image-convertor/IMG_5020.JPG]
texture-to-image_1


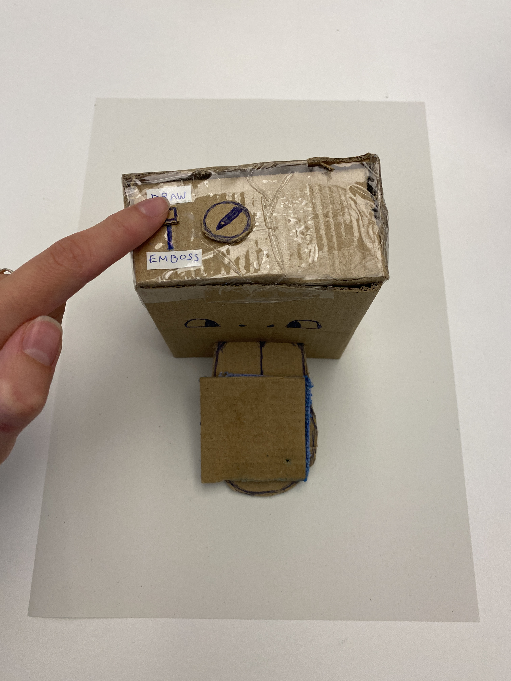
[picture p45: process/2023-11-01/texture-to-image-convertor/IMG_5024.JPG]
texture-to-image_1


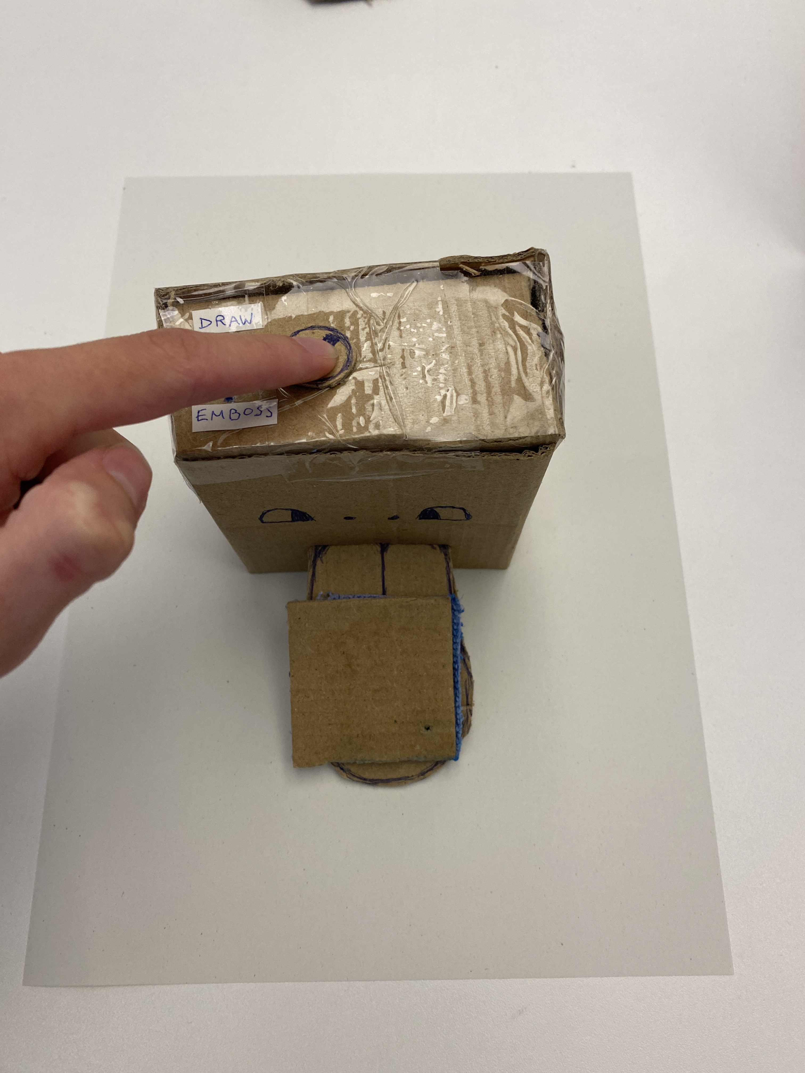
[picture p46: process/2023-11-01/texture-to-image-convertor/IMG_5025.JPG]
texture-to-image_1


Once a drawing button is pressed, the assistant creates an abstract illustration inspired by your texture.

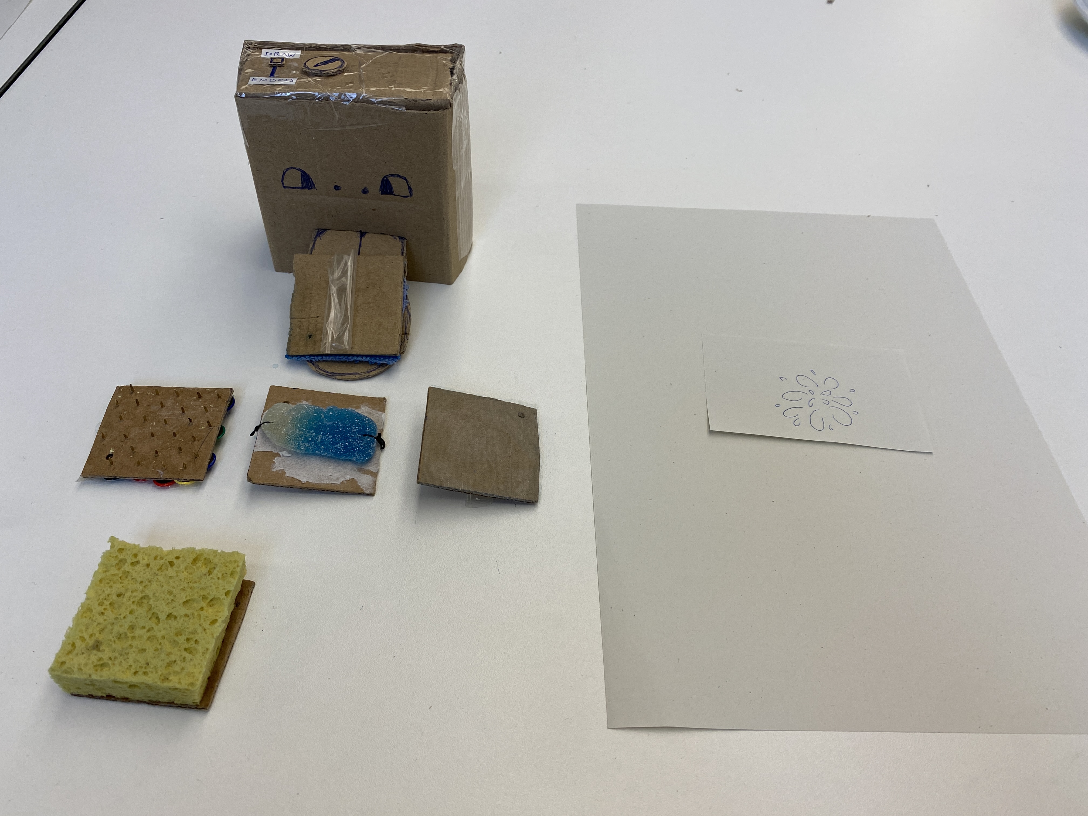
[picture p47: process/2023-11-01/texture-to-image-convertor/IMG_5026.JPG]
texture-to-image_1


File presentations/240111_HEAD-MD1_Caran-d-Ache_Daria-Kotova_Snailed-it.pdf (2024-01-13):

Daria Kotova
Snailed-it
Master Media Design 1 | 17-01-2024
Caran d’Ache
Future of Drawing

# Snailed-it

# Kick start your drawings

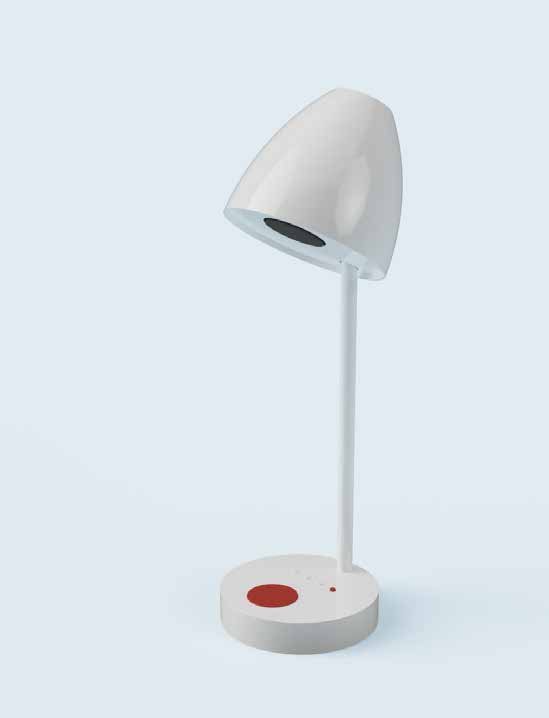
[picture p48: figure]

# Project Description

Snailed-it is an AI assistant that helps you start your artistic explorations, sometimes with an unexpected touch. Tailored for people looking for ways to occupy their free time, Snailed-it is a perfect companion for those open to drawing but unsure where or how to begin. Thanks to Snailed-it, you can now use any small object you find as a starting point. The assistant projects your object based on the settings you choose, so that you can then trace it. Snailed-it can be used in any comfortable setting, as long as it is placed on a flat surface. So, whether you are at home or in the office, the creative possibilities are at your fingertips.

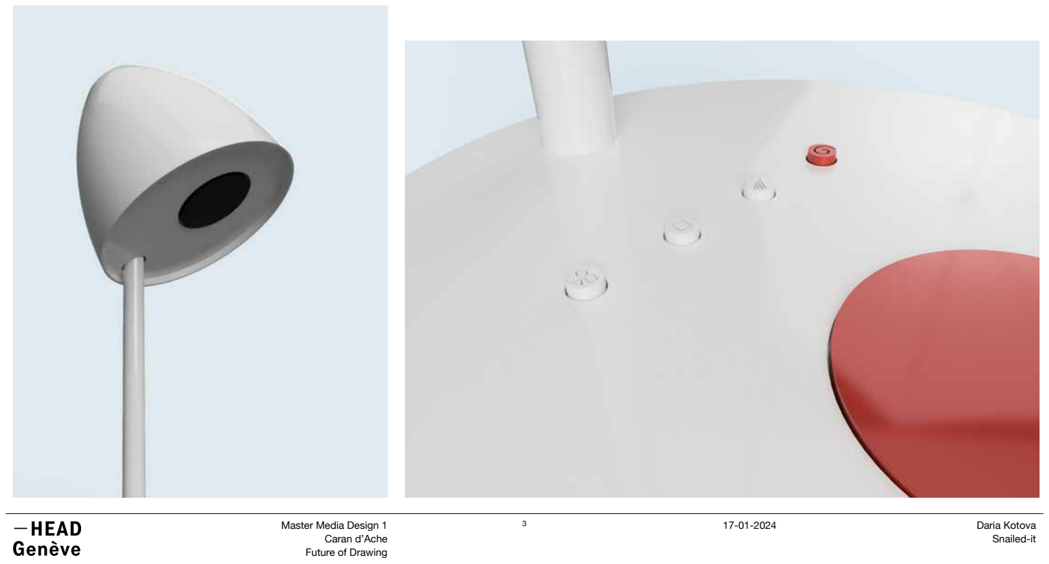
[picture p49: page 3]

# User Journey

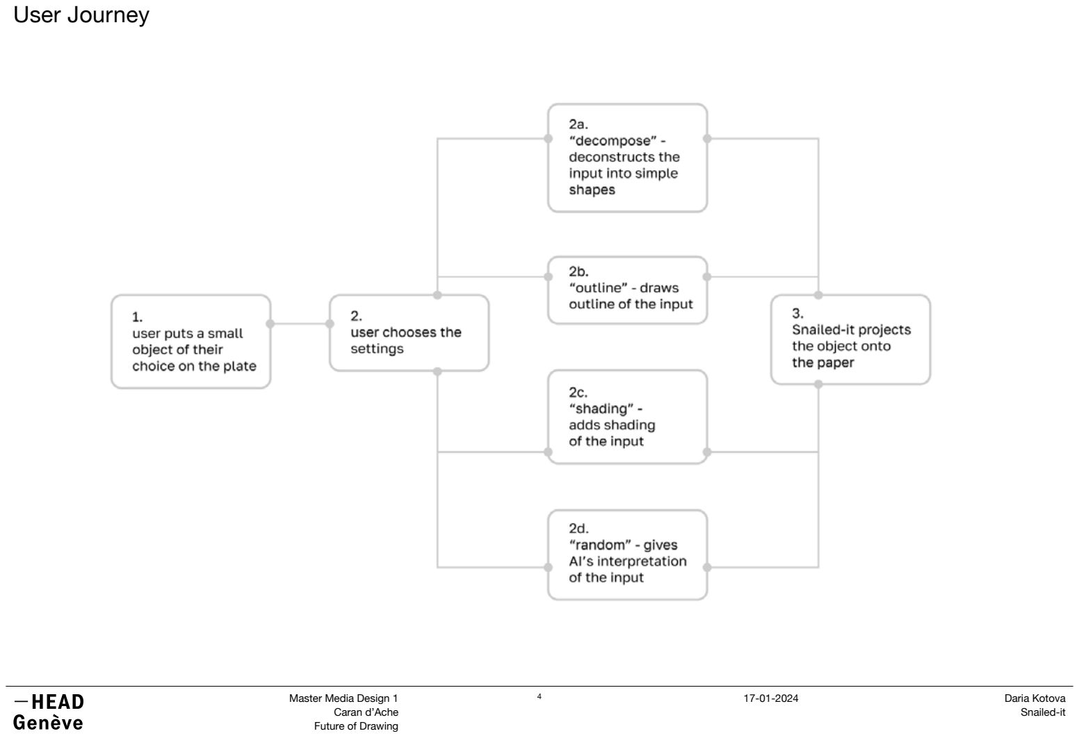
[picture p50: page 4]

# Field observations

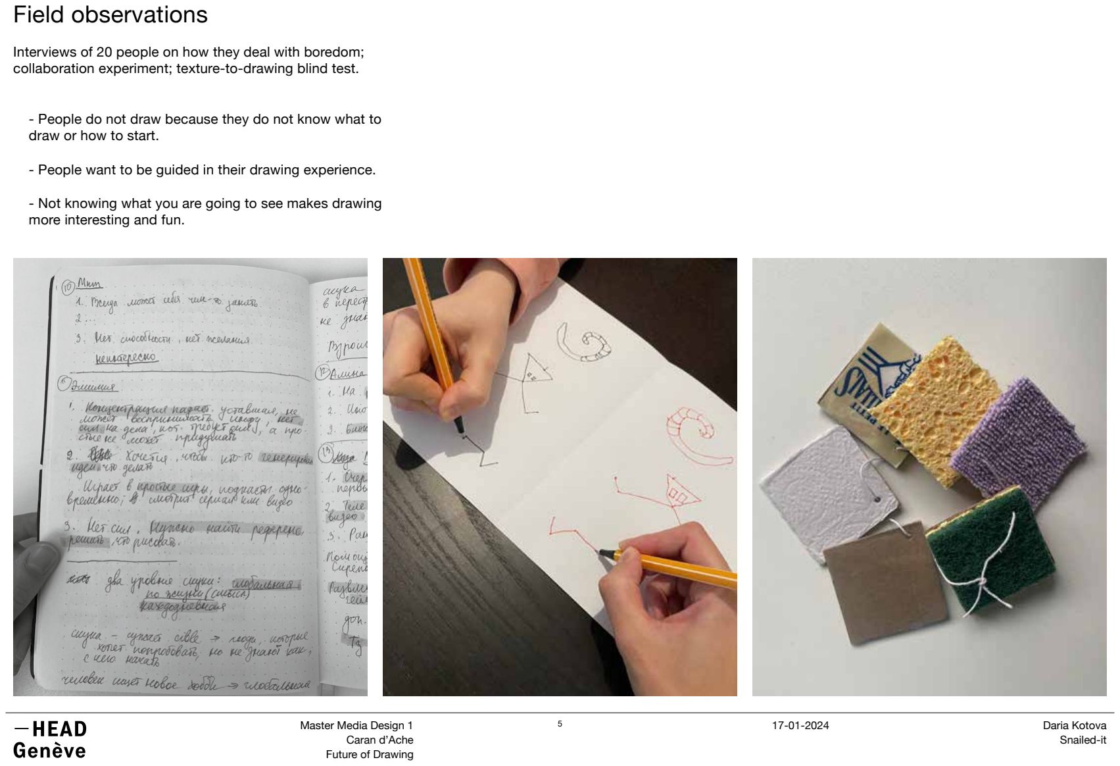
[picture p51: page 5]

Interviews of 20 people on how they deal with boredom; collaboration experiment; texture-to-drawing blind test.

- People do not draw because they do not know what to draw or how to start.
- People want to be guided in their drawing experience.
- Not knowing what you are going to see makes drawing more interesting and fun.

# Visual and Material Moodboard

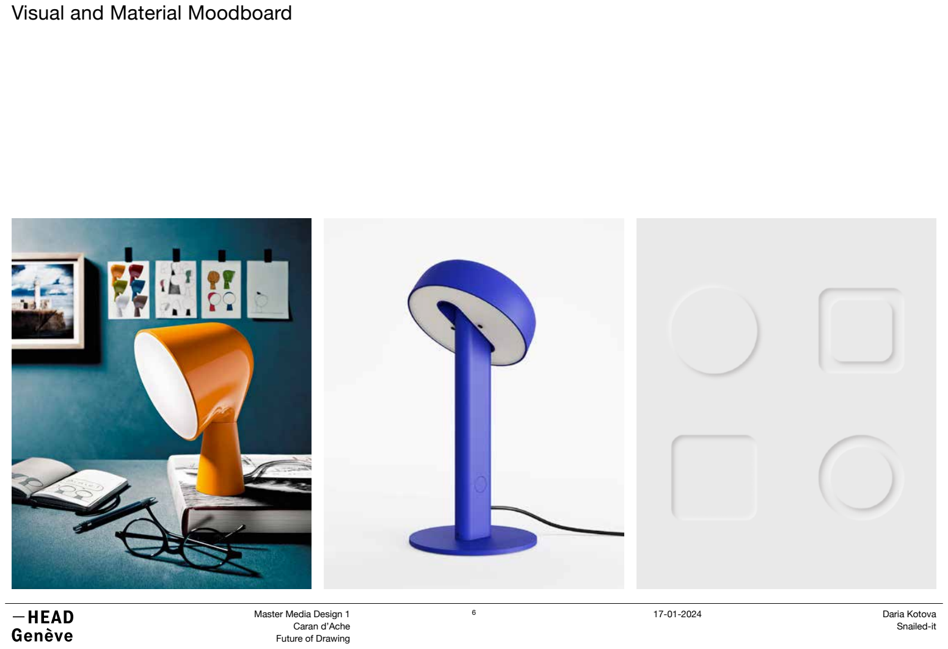
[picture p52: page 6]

# Shape research

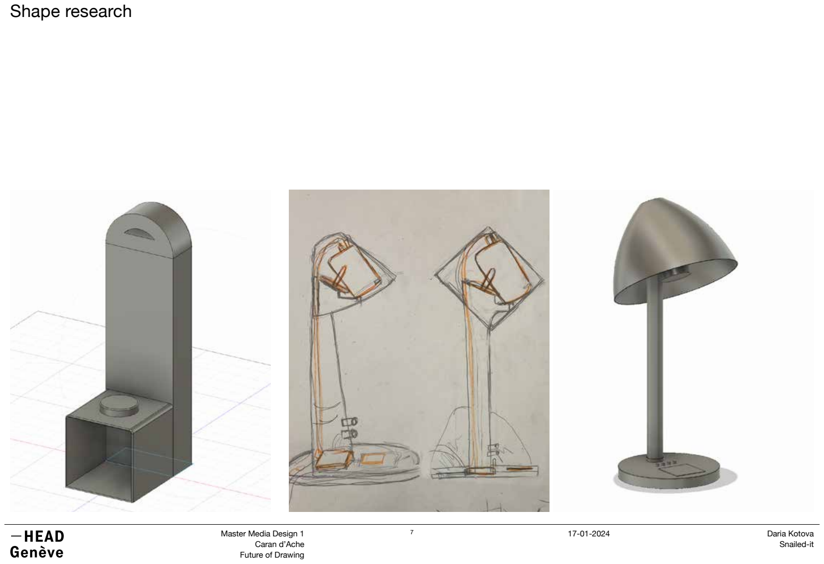
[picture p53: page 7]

# Paper Prototypes

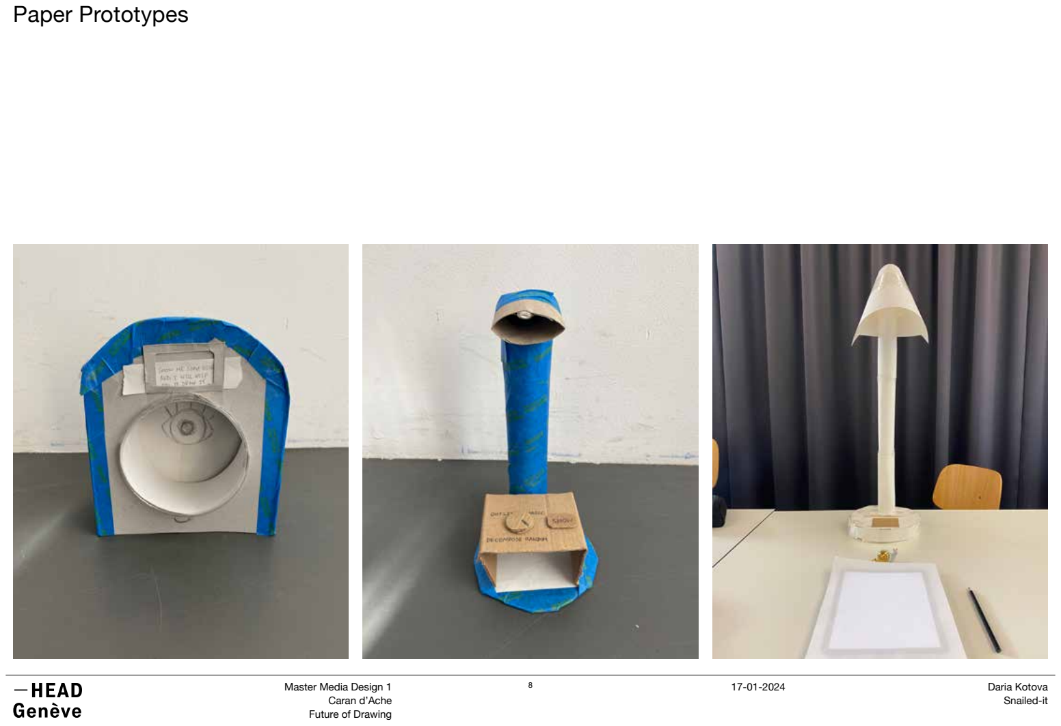
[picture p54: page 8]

# User Tests

Pictures and/or videos of the user tests of your prototypes. Beetroot water spinach okra water chestnut ricebean pea catsear courgette summer purslane. Water spinach arugula pea tatsoi aubergine spring onion bush tomato kale radicchio turnip chicory salsify pea sprouts fava bean. Dandelion zucchini burdock yarrow chickpea dandelion sorrel courgette turnip greens tigernut soybean radish artichoke wattle seed endive groundnut broccoli arugula.

# Electronics

Electronic schematic | Fritzing schematic (optional)

# Plan Drawings

Materials: Material Material
Scale: 1:XX in mm (scale of the plan in the presentation document) Overall dimensions are sufficient.
Front view

Perspective
Right view

Top view

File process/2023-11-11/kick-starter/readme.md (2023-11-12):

# Kick-starter

## Description

This assistant creates outlines of small objects that you can find around you and it thus helps you to overcome the problem of not knowing how to start a drawing.

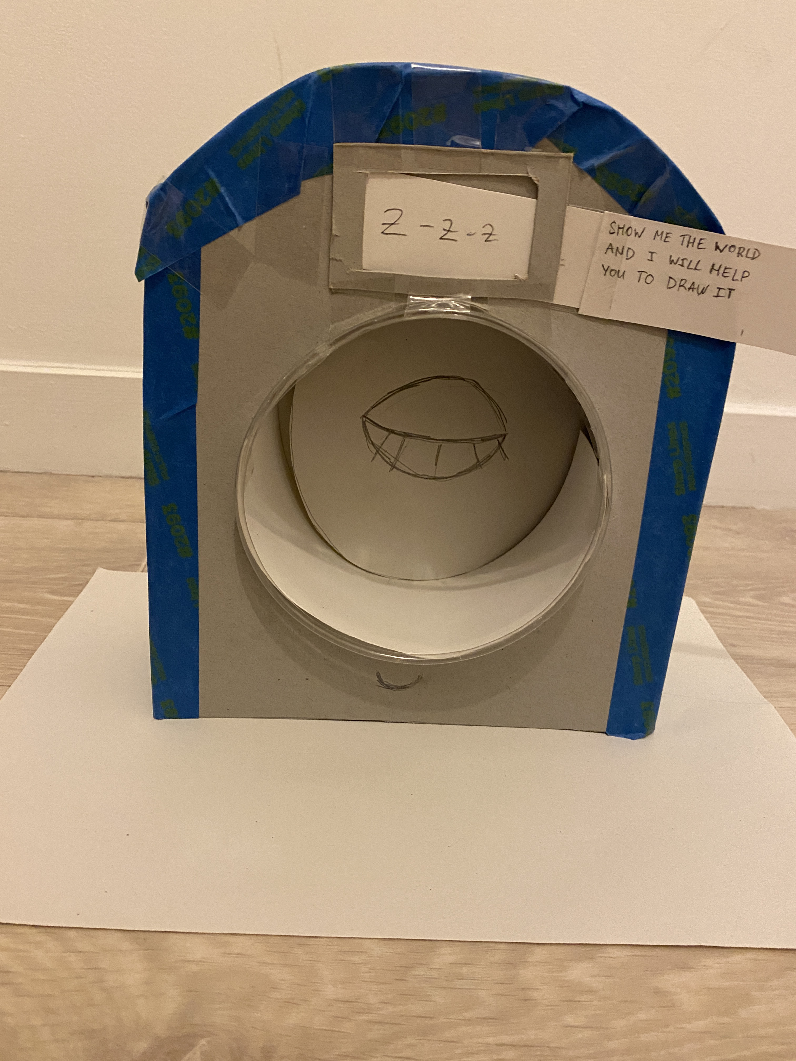
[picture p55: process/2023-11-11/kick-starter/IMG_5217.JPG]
kick-starter-1
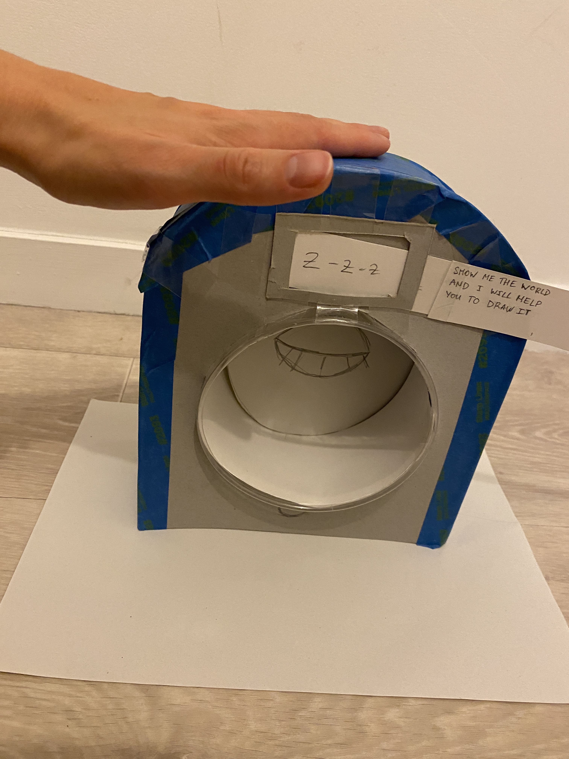
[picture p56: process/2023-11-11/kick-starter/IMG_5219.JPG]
kick-starter-2
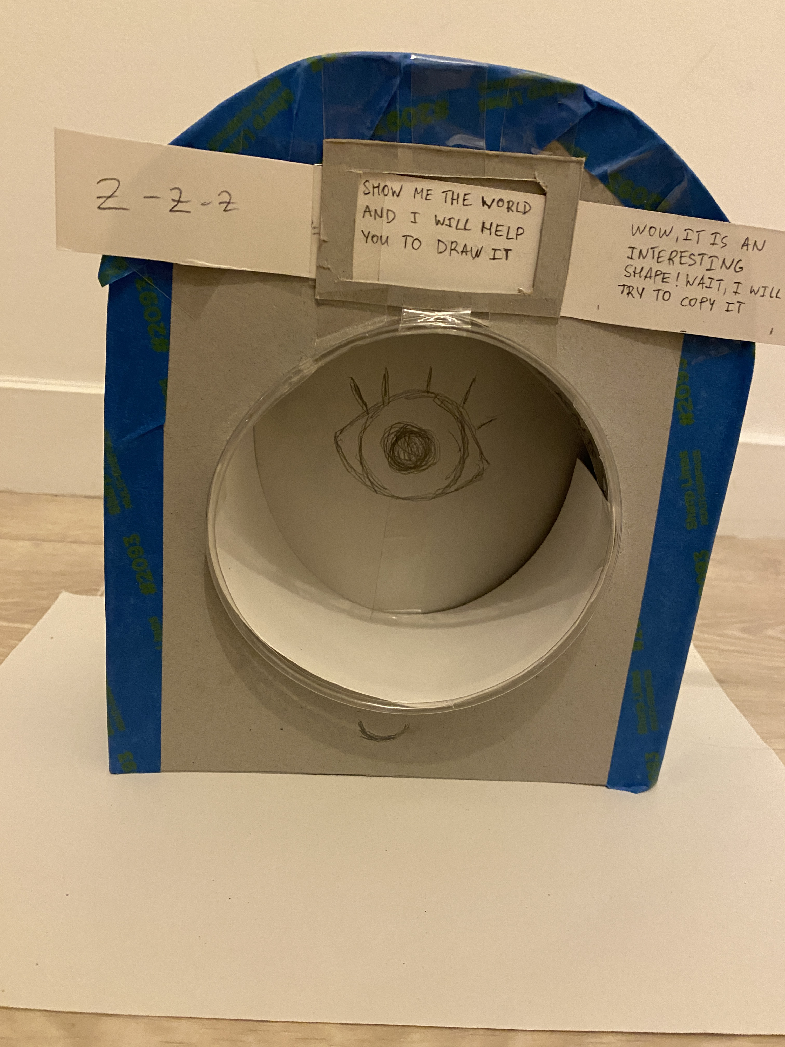
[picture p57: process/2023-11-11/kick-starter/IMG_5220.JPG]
kick-starter-3
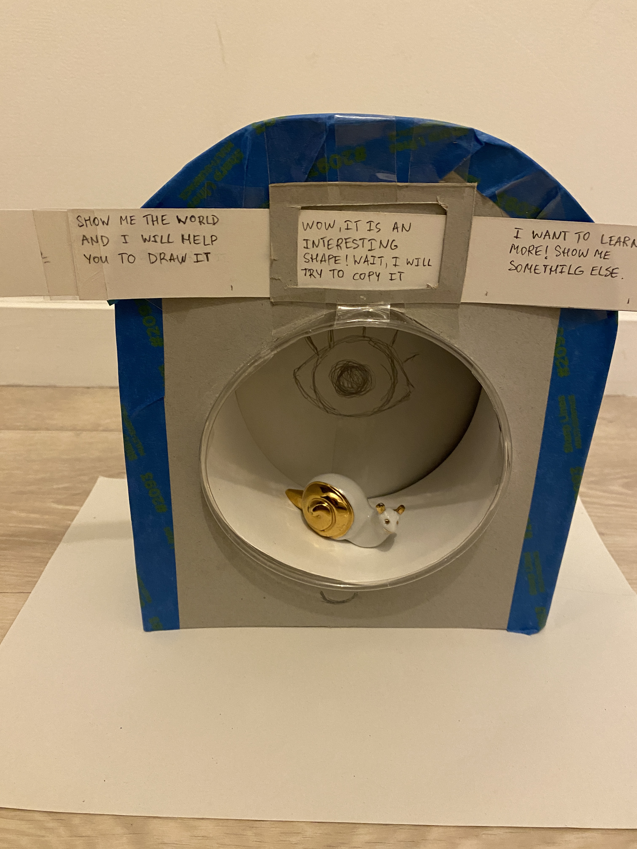
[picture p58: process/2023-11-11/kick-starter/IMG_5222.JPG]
kick-starter-4
 The user wakes up the assistant, places an object in it.   
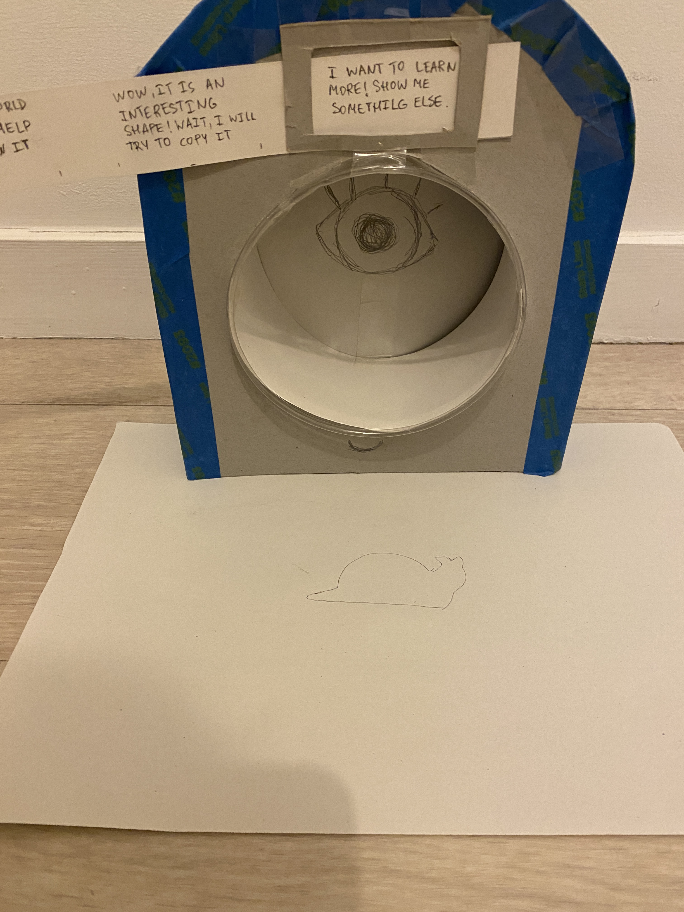
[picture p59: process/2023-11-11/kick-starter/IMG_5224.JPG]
kick-starter-5
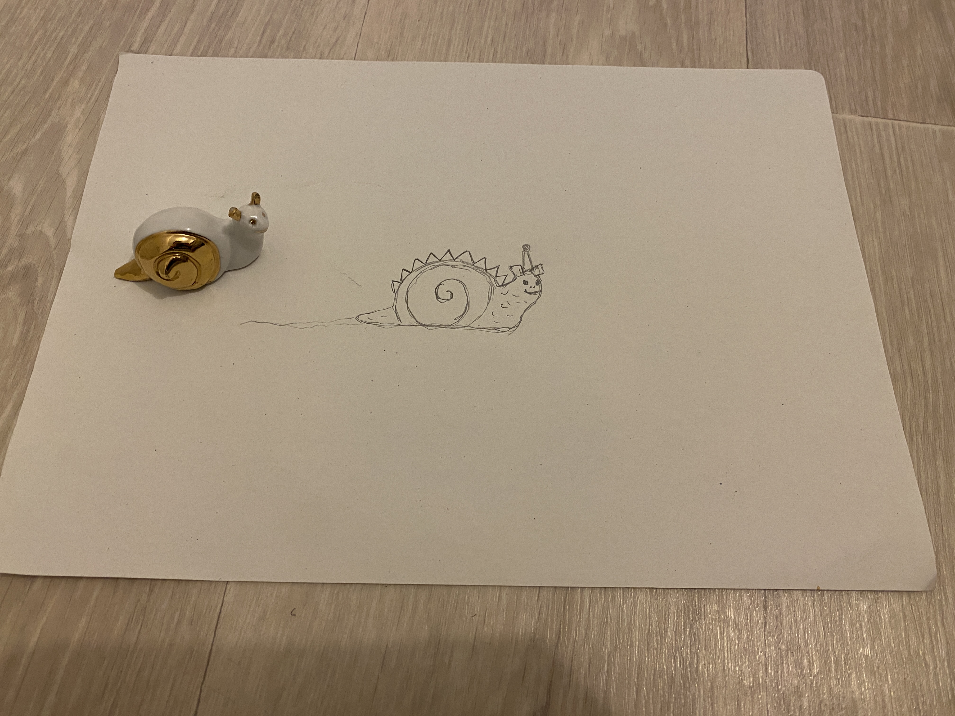
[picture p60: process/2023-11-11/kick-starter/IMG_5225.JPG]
kick-starter-6
Assistant analyses the object and draws its outline that serves as a starting point for a drawing.

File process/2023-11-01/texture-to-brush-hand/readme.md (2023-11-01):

# Texture-to-brush hand

## Description

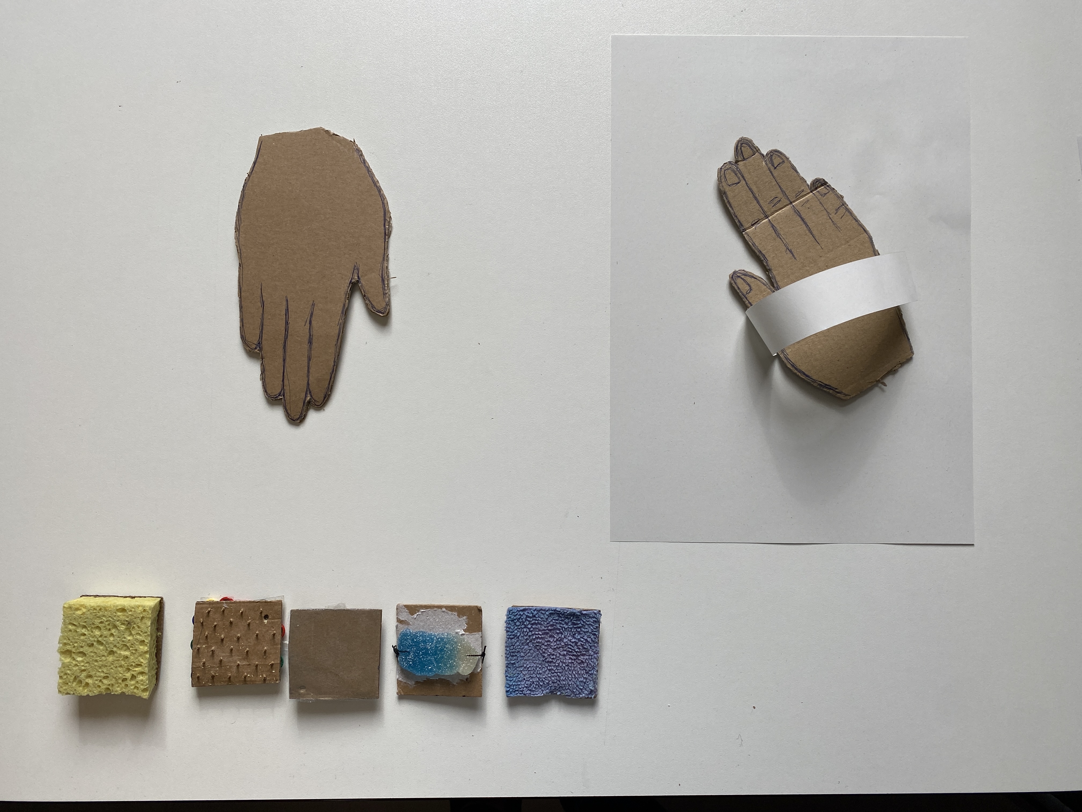
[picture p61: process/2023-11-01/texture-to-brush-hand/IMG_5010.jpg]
texture-to-brush-hand-1
 This device is used to turn any texture into a brush. It consists of two hands. The first one detacts textures that you give to it and then transfers information about them to the second hand. The second hand can be put on your own hand and be used to draw with a "brush" created from your texture.

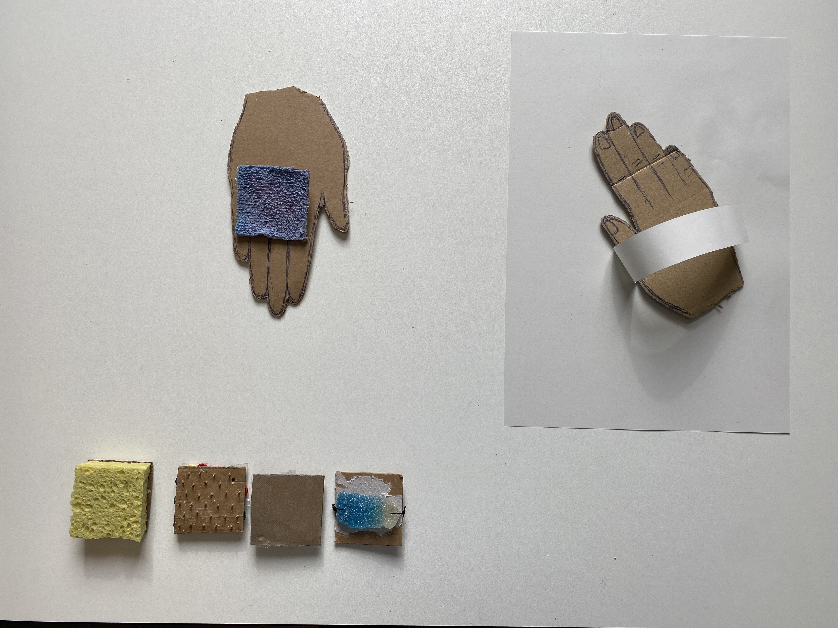
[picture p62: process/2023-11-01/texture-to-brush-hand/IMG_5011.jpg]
texture-to-brush-hand-2


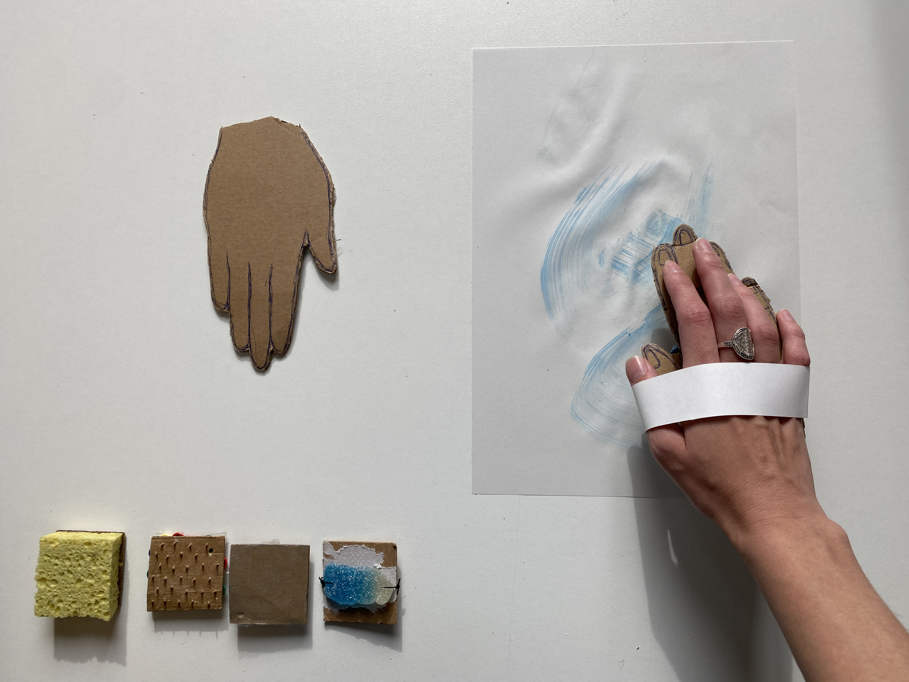
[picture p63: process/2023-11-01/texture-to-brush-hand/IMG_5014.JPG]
texture-to-brush-hand-3


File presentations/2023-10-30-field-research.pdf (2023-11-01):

Daria Kotova | MMD 1 | HEAD 2023

## Field research

# PLAYFUL AI CREATIVE ASSISTANT

# BOREDOM?

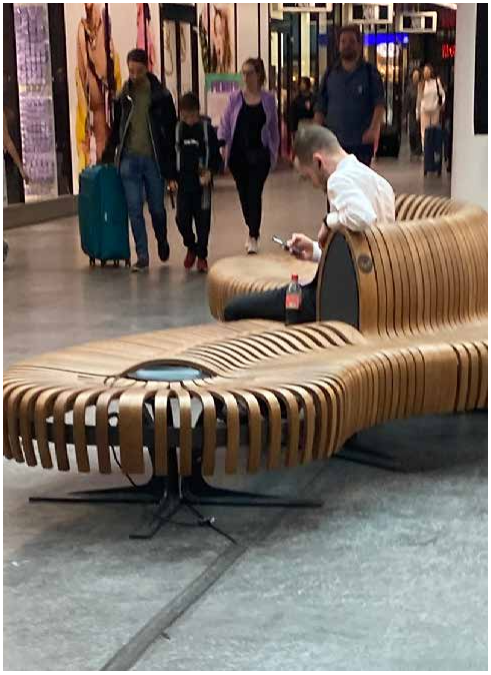
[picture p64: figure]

## Observations (airport)


Scrolling
Reading
People watching

## Observations (airport)

Scrolling
Reading
Can only assume that people are bored | People watching

## Interwiews (20 respondents)


1. In what situations or places can you get bored?
2. How do you deal with your boredom?
3. What stops you from drawing in these moments?

## Interwiews (20 respondents)


1. In what situations or places can you get bored?
2. How do you deal with your boredom?
3. What stops you from drawing in these moments?
1. At home alone, at school, on transport, waiting, no energy, monotonous tasks, boring topic

## Interwiews (20 respondents)


1. In what situations or places can you get bored?
2. How do you deal with your boredom?
3. What stops you from drawing in these moments?
2. Music, videos, reading, writing, conversations, walks, scrolling, sketching, games, chores, sleep
1. At home alone, at school, on transport, waiting,
no energy, monotonous tasks, boring topic

1.

# NOT EVERYONE SUFFERS FROM BOREDOM

2.

# NOT EVERYONE SCROLLS ALL THE TIME

3.

# EXISTENTIAL BOREDOM

4.

# DON’T DRAW BECAUSE DON’T HAVE TOOLS OR IDEAS

## First intention


Playful AI assistant who:
- can give an idea of what to draw
- can give instructions and accompany
- does it in a fun way (gamification)
- becomes your drawing partner.
Clippy | Eilik

SketchAR

- Giving instructions
- Drawing with a partner
- Monotony
- Ways to draw without stress

## Topics to look into

SketchAR

## Drawing with a partner


# MONOTONOUS TASKS?

5.

# MONOTONY IS NOT A REAL ISSUE

# HUMAN <-> ASSISTANT

dialogue

What for?
- accompany
- try new stuff
- distract
- entertain

How?
- fun and easy (no energy, do not know how to start)
- unusual input (no equipment, busy hands)

textures <-> drawing
smells <-> drawing

## Textures <-> drawing


1. Fun and playful
2. Enhances your senses
3. Forces you to think in new ways
4. May not feel safe
5. Some people focus on understanding what the object is

## Smells <-> drawing


1. Smells are more associated with feelings or memories
2. Smells are less invasive
3. Smells may cause frustration from not knowing

## Emotions <-> drawing


1. Similar patterns
2. The notion of pressure - (texture?)

# EMOTIONAL DRAWING ASSISTANT

emotions -> lines + textures -> drawing


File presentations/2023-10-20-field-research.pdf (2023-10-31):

Daria Kotova | MMD 1 | HEAD 2023

## Field research

# PLAYFUL AI CREATIVE ASSISTANT

# BOREDOM?


## Observations (airport)


Scrolling
Reading
People watching

## Observations (airport)

Scrolling
Reading
Can only assume that people are bored | People watching

## Interwiews (20 respondents)


1. In what situations or places can you get bored?
2. How do you deal with your boredom?
3. What stops you from drawing in these moments?

## Interwiews (20 respondents)


1. In what situations or places can you get bored?
2. How do you deal with your boredom?
3. What stops you from drawing in these moments?
1. At home alone, at school, on transport, waiting, no energy, monotonous tasks, boring topic

## Interwiews (20 respondents)


1. In what situations or places can you get bored?
2. How do you deal with your boredom?
3. What stops you from drawing in these moments?
2. Music, videos, reading, writing, conversations, walks, scrolling, sketching, games, chores, sleep
1. At home alone, at school, on transport, waiting,
no energy, monotonous tasks, boring topic

1.

# NOT EVERYONE SUFFERS FROM BOREDOM

2.

# NOT EVERYONE SCROLLS ALL THE TIME

3.

# EXISTENTIAL BOREDOM

4.

# DON’T DRAW BECAUSE DON’T HAVE TOOLS OR IDEAS

## First intention


Playful AI assistant who:
- can give an idea of what to draw
- can give instructions and accompany
- does it in a fun way (gamification)
- becomes your drawing partner.
Clippy | Eilik

SketchAR

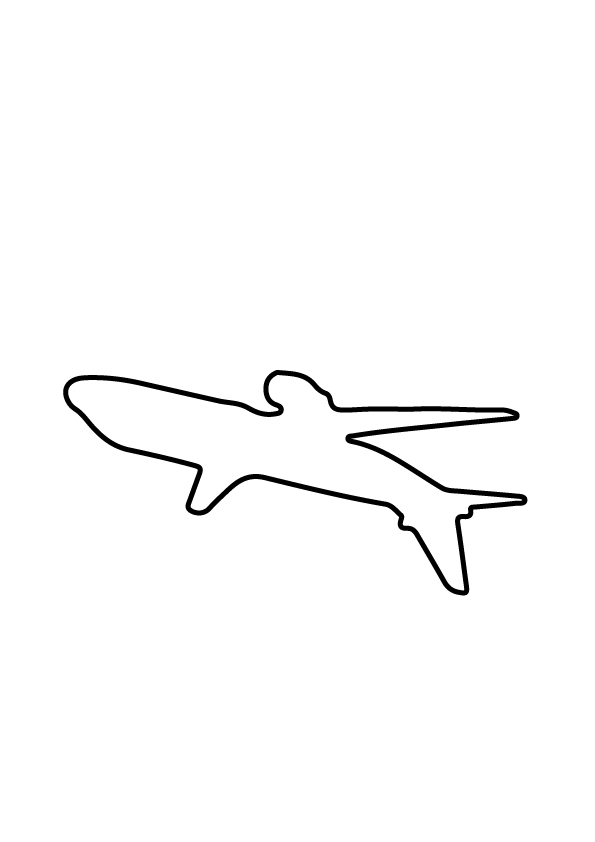
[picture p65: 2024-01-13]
electronics/code/images/outlines/outline-plane.jpg

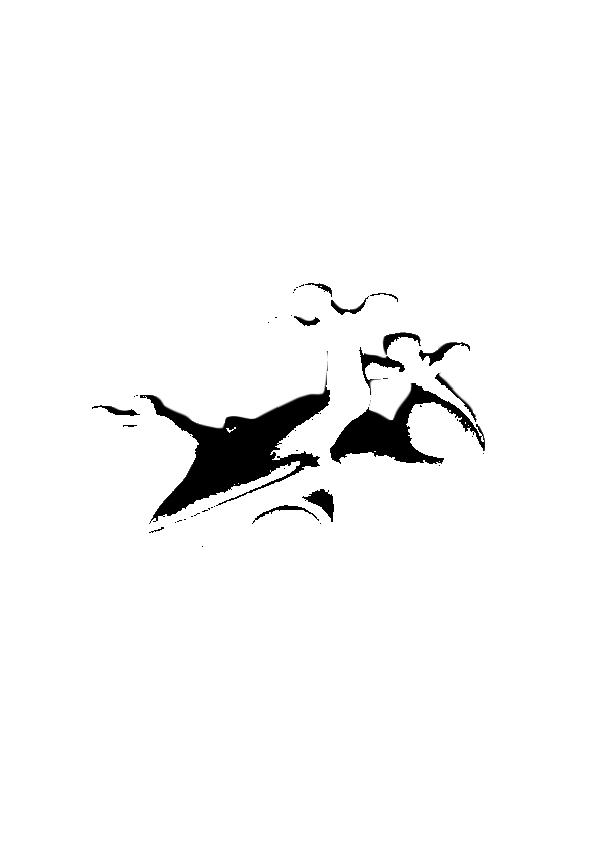
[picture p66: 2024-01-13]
electronics/code/images/shading/shading-frog.jpg

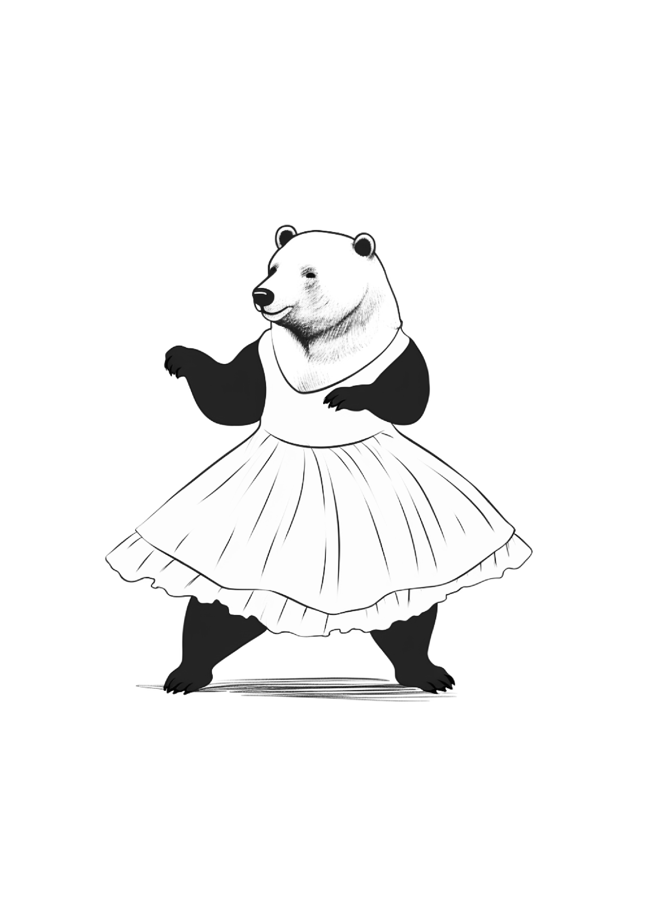
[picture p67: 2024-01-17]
electronics/code/images/random/random-bear.jpg

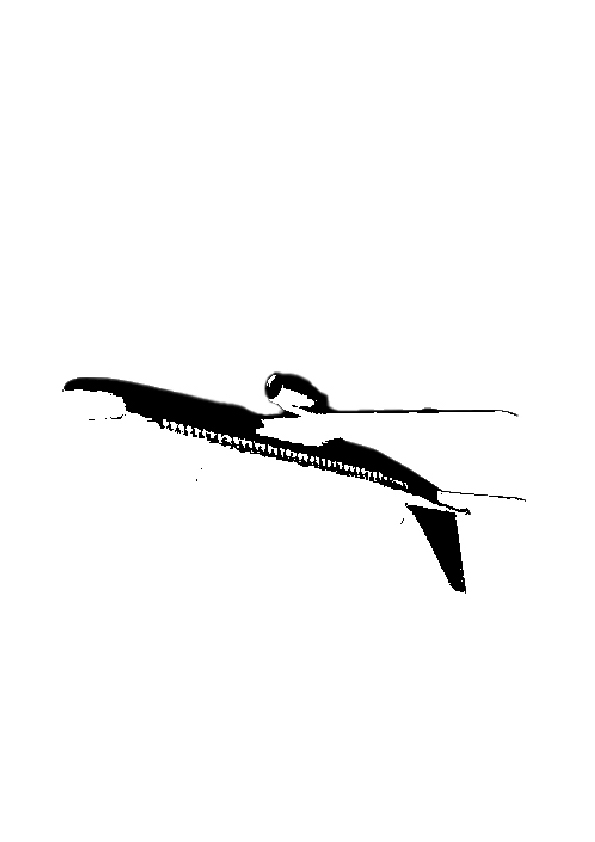
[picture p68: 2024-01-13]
electronics/code/images/shading/shading-plane.jpg

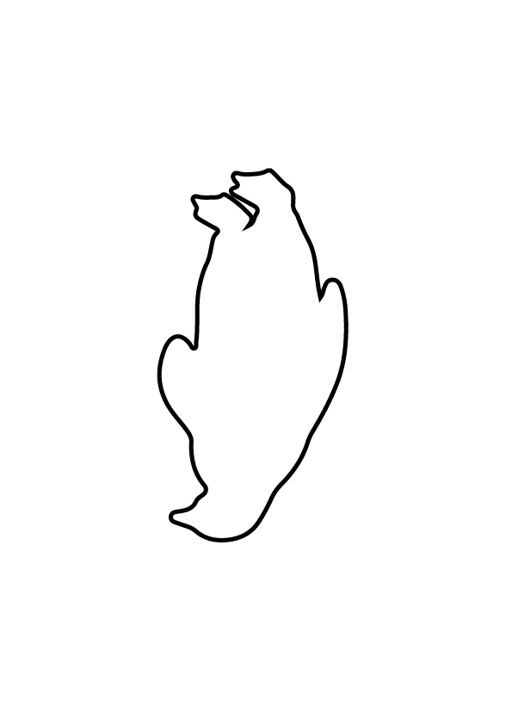
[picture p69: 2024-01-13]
electronics/code/images/outlines/outline-penguin.jpg

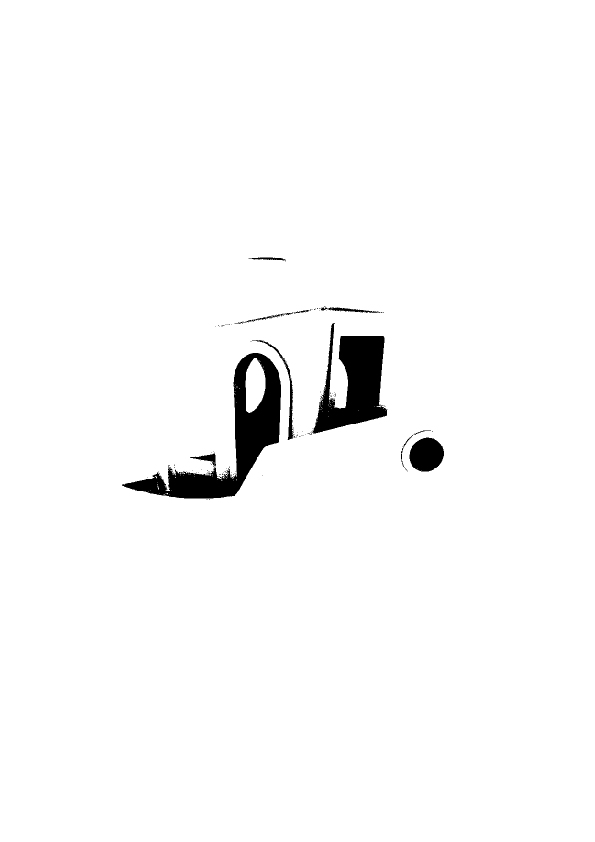
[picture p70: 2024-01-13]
electronics/code/images/shading/shading-ship.jpg

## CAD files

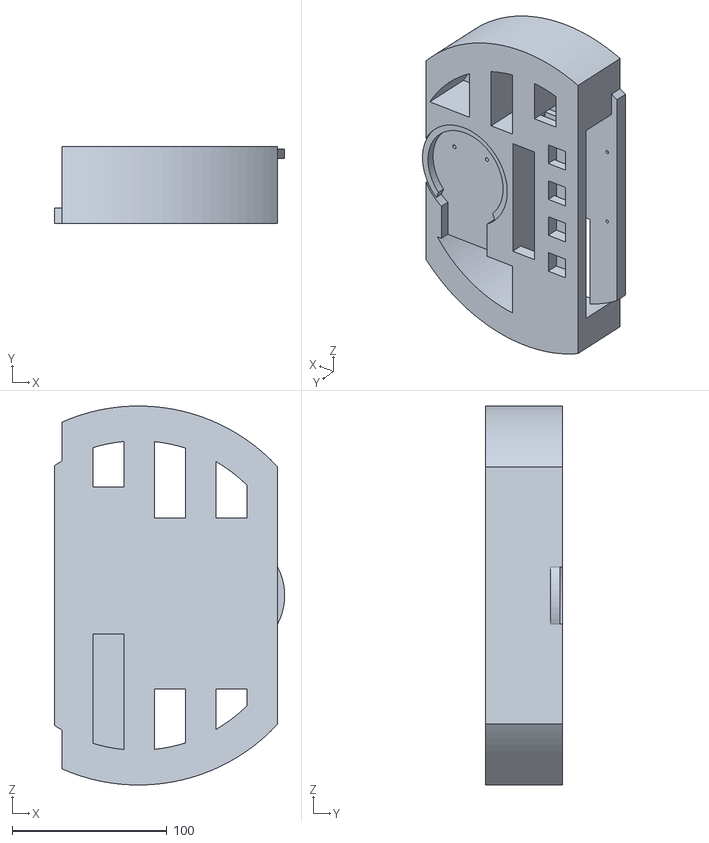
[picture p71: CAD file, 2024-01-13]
form/3d-parts/base_main.stl
148.9 x 49.5 x 245.0

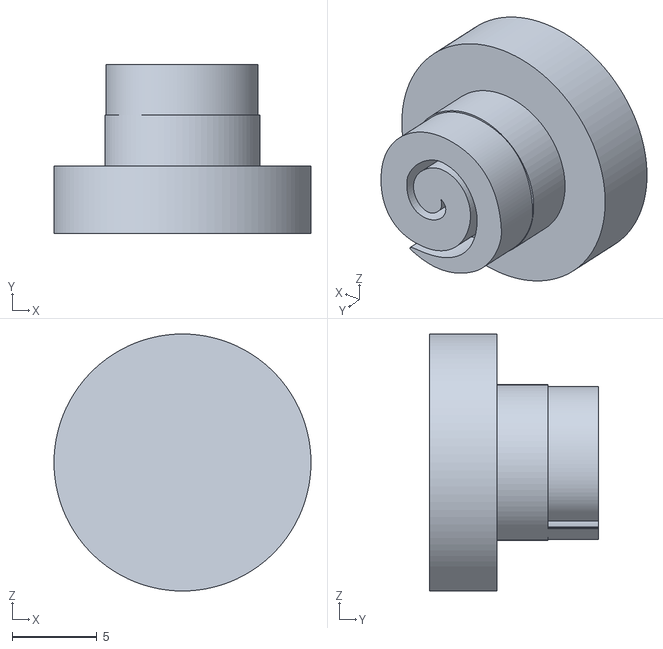
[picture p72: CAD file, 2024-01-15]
form/3d-parts/button4-3.stl
15.2 x 10.0 x 15.2

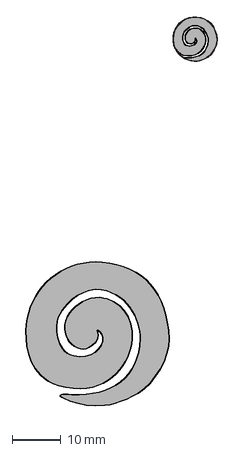
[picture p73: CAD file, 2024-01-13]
form/buttons-icons/swirl.dxf
39.9 x 81.3 mm

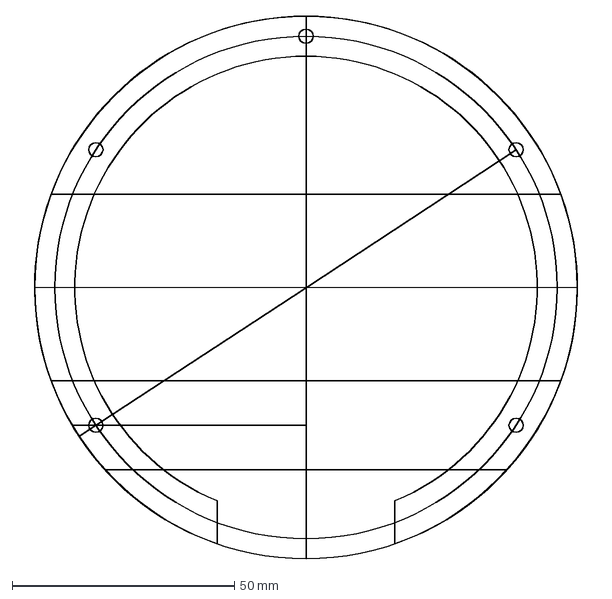
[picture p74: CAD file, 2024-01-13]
form/laser_cut/disk2.dxf
130.2 x 122.0 mm

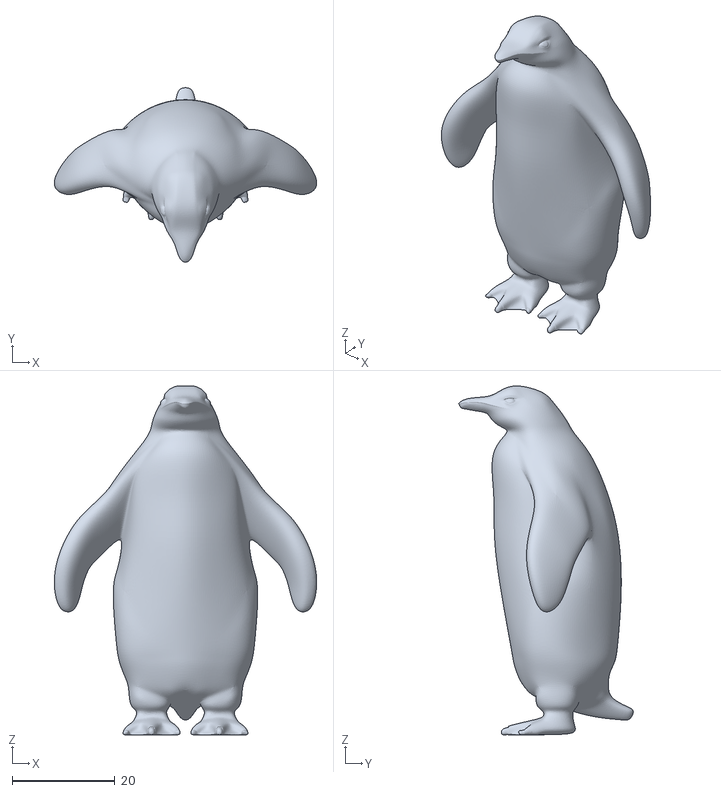
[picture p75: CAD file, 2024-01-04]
process/2024-01-04/Penguin_t.stl
51.2 x 34.0 x 68.1

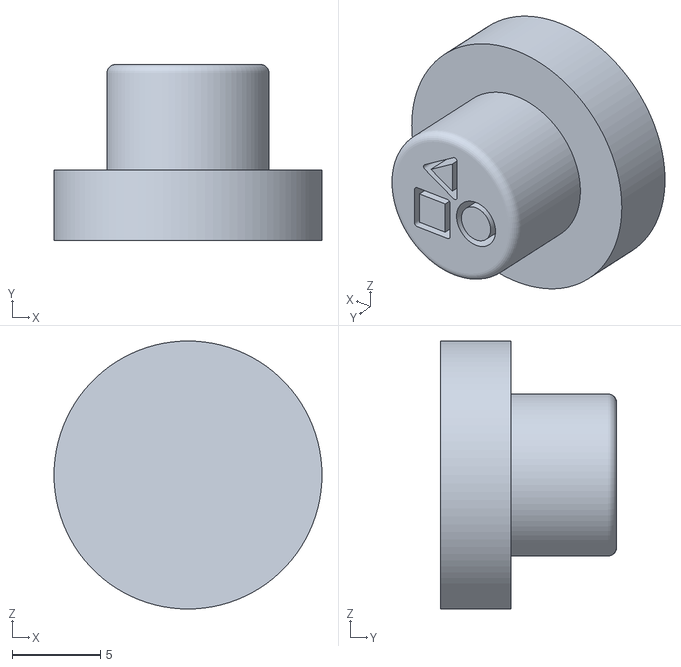
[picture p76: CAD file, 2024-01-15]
form/3d-parts/button1-3.stl
15.2 x 10.0 x 15.2

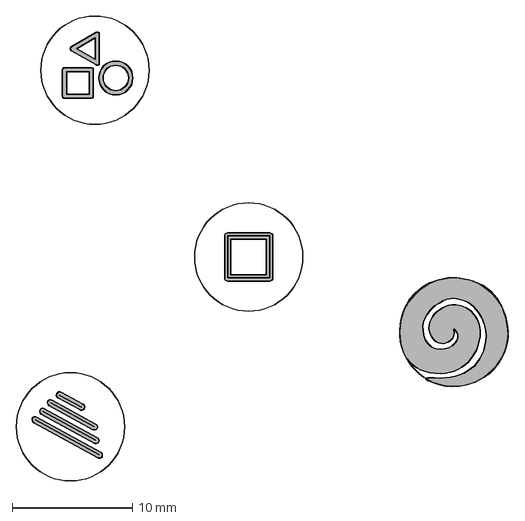
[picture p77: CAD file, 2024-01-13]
form/buttons-icons/icons.dxf
40.9 x 38.6 mm

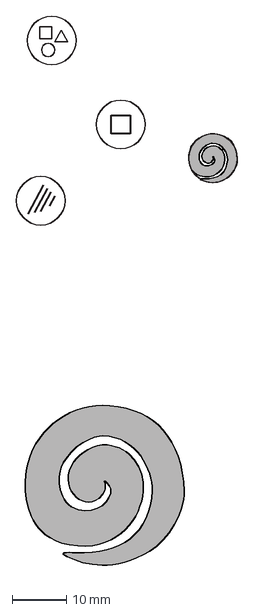
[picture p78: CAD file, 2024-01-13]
form/laser_cut/forms.dxf
40.9 x 102.9 mm

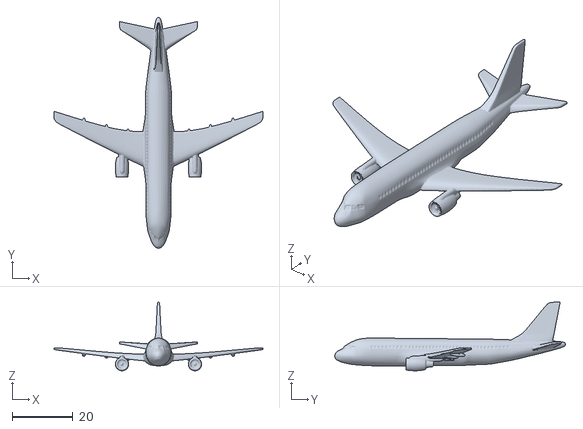
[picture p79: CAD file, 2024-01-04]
process/2024-01-04/Plane_t.stl
68.5 x 75.7 x 22.5

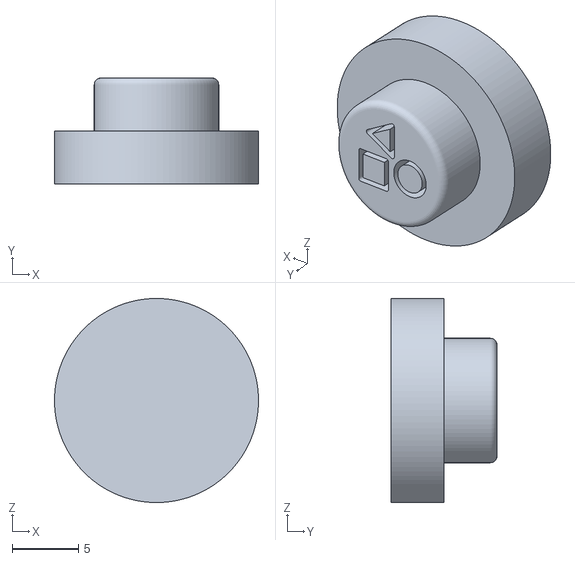
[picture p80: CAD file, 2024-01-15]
form/3d-parts/button1_2.stl
15.4 x 8.00 x 15.4

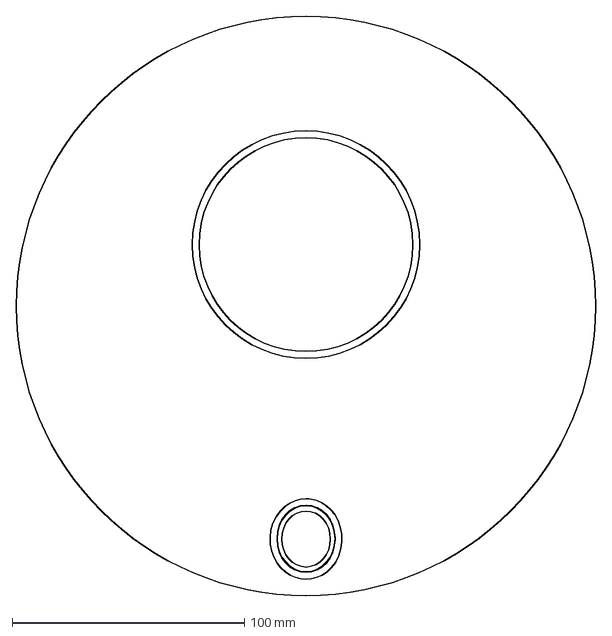
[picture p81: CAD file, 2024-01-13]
form/laser_cut/diffusor.dxf
249.4 x 249.4 mm

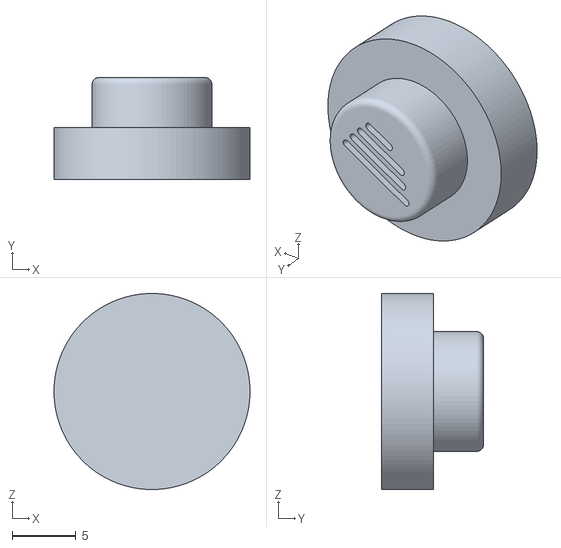
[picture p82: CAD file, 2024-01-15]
form/3d-parts/buttom3-2.stl
15.4 x 8.00 x 15.4

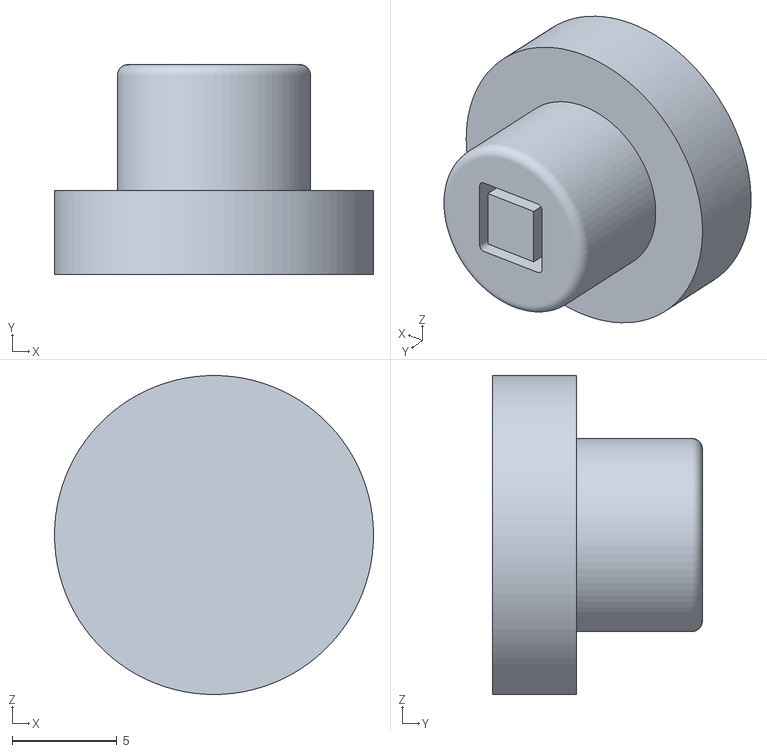
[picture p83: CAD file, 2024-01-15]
form/3d-parts/button2-3.stl
15.2 x 10.0 x 15.2

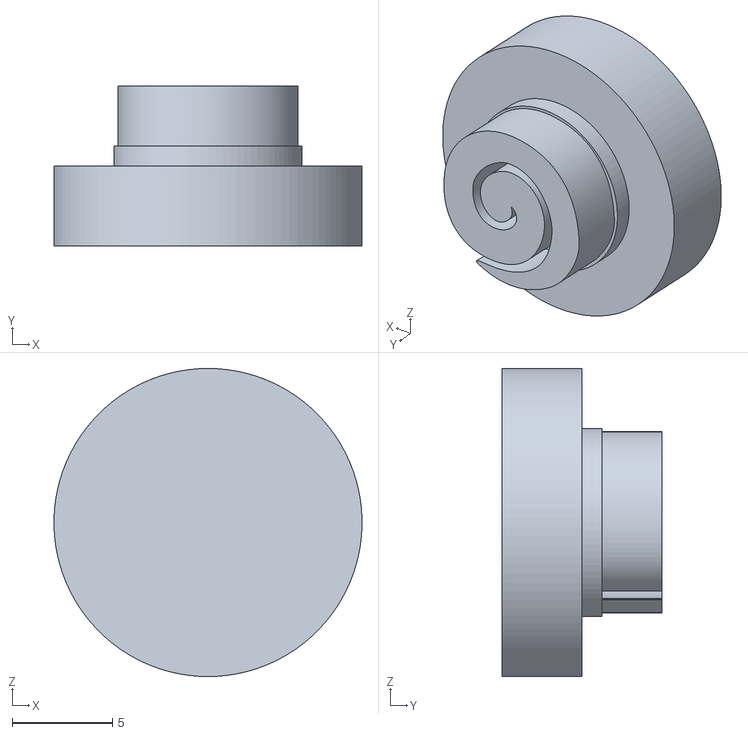
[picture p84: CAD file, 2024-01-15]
form/3d-parts/button4-2.stl
15.4 x 8.00 x 15.4

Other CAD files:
form/3d-parts/buttom3-3.stl
form/3d-parts/button2-2.stl
form/3d-parts/4_2.stl
form/3d-parts/2.stl
form/2023-12-21/snailed_it v20.f3d
form/3d-parts/3.stl
form/3d-parts/4.stl
form/3d-parts/Body60.stl
form/3d-parts/Clamp Front.stl
form/3d-parts/Shade Back.stl
form/3d-parts/Shade Front.stl
form/3d-parts/buttom3.stl
form/3d-parts/button1.stl
form/3d-parts/button2.stl
form/3d-parts/button4.stl
form/fusion360/Daria-Kotova_Snailed-it v1.f3d
form/fusion360/snailed_it v16.f3d
form/fusion360/snailed_it_final.f3d

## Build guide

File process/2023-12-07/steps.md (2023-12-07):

# All the Steps to Build Snailed-it

## Form
- 3D Modelling (Fusion 360)
    - Base with space for electronics
    - Leg + fixations for the projector
    - Shell (head)
   
## Materials

- Wood (for first prototype to check if the dimensions are ok)
    - Talk to people at Wood Pool 

- Metal (for base, leg and fixations)
    - Talk to people at Metal Pool

- 3D printing (for head, buttons??)

- Something to cover projector and Raspberry Pi power cables (cloth thingy with velcro?)

- Paint

## Electronics

- Raspberry Pi
    - Code
        - Install Linux
        - Detection of RFID tags
        - Get an image based on the tag and chosen parameters
        - Teach AI to recognize objects with a camera (in a perfect world)
    - Input
        - 3 buttons
        - Potentiometer
        - NFC tags and RFID reader
        - camera (in a perfect world)
    - Output
        - projector (BeamBuddy for now, Pico projector in a perfect world)
        
- Wiring
    - projector <-> Pi (HDMI)
    - Pi <-> buttons
    - Pi <-> potentiometer
    - Pi <-> RFID reader

- Power
    - Projector power cable
    - Raspberry Pi power cable

- API (in a perfect world)

## Others

- Choose 5 objects
- Prepare a pool of output images
- Learn AI image recognition

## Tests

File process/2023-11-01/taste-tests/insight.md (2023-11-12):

# Insights

People found it difficult not to focus on the form, texture and smell. The samples were immediately recognized, which made the test biased.

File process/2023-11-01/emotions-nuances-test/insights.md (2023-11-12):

# Insights

1. Trying to depict nuances of emotions made people think much harder, it seemed that they felt uncomfortable.
2. Overall, the lines showed similar patterns.

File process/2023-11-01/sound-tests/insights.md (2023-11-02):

# Insights

There was a strong correlation between the sounds and their visual interpretation by participants, not much variation. The test did not spark much interests and was the least favourite.

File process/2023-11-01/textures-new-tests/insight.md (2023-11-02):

# Insights

1. Radical textures (pins and jelly) seemed to be easier to guess.
2. Asking to draw a texture instead of an association gives more consistent but less interesting results.
3. Participants admitted that they enjoyed the mystery aspect of the test, when they do not know what will be next.

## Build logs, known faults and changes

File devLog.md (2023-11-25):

# DevLog

This is a file with my day-to-day progress on the project with Caran d'Ache on the future of drawing.

## 2023-11-25

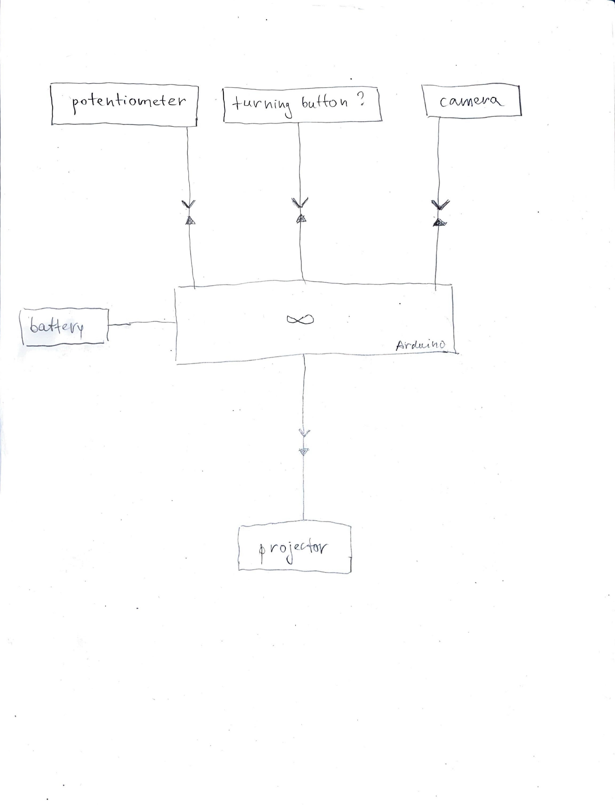
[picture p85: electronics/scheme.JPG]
scheme
Added electronics scheme 

## 2023-11-16

Had mid [presentation](/presentations/HEAD-MD1_Caran-d-Ache_Daria-Kotova_Snailed-it.pdf) with Caran d'Ache.

Feeling awesome afterwards. On Monday morning I felt very frustrated and anxious, because I did not know if my idea made sense and was doable. But after several feedbacks on Monday, Wednesday and today, I feel quite reassured and somewhat relieved. I am also happy to finally understand what exactly I want to do. My project now has a mystery aspect, which I wanted to introduce but did not know how.

I sensed some excitement from Laure whenever she started asking if you can put my object on the table or on the floor or wherever. Do not know if Sophie liked it, she asked some clarifying question about the learning aspect, but I guess that is the topic that interests her in general.

Insights from this week: I need to plan wisely and the most important one is that I should ask for some feedback before judging myself (dah).

No idea how to start the electronics and how to improve my prototype but I will just trust the process and go with the flow. Peace.

## 2023-11-15

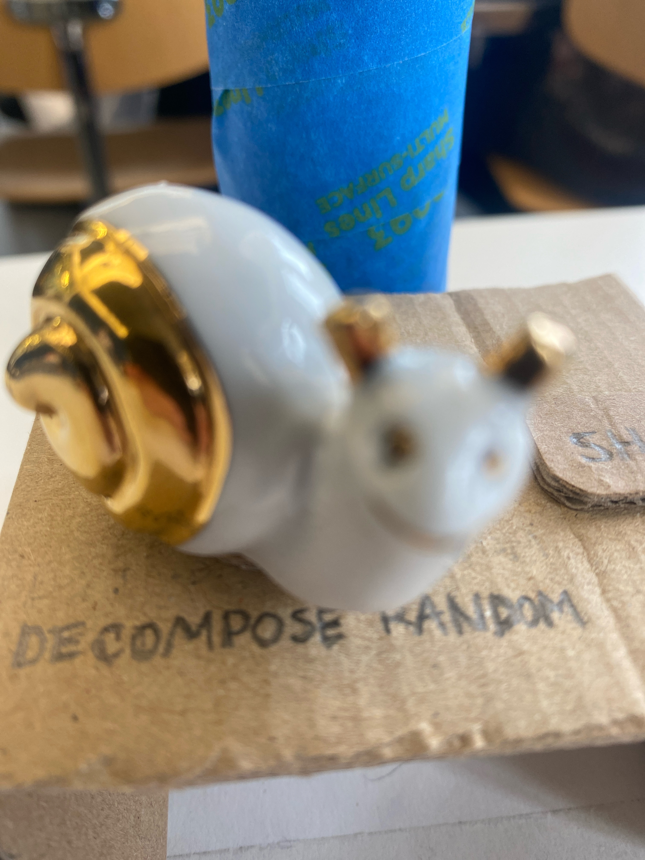
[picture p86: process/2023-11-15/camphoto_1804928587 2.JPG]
snail
Finished slides for mid-presentation. Changed the name of the project to Snailed-it. Snailed-it because you nailed it :) but also because of the snail 

Also did some [user tests](/process/2023-11-15/user-tests/) for my last prototype, generated [Midjourney](/process/2023-11-15/midjourney/) illustrations to show the possible weirdness of AI's interpretations, as well as created various projection [outputs](/process/2023-11-15/output/).

## 2023-11-14

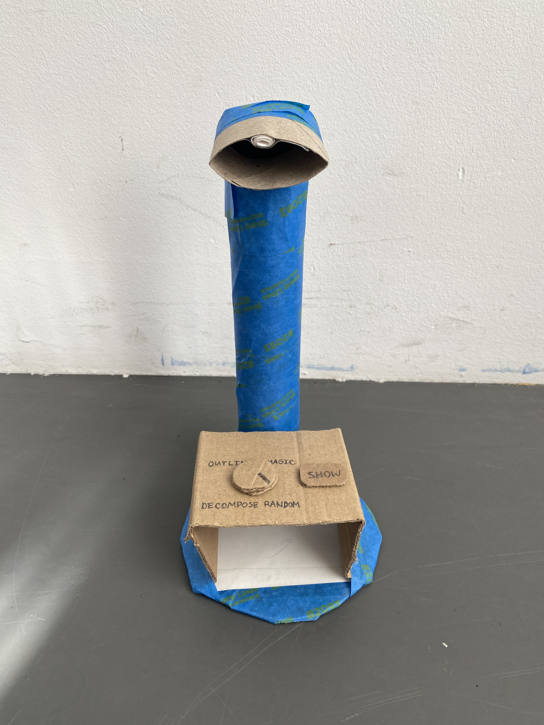
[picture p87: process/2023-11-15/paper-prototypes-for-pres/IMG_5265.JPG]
prototype
Today I made a new paper prototype based on Laure's feedback. It kinda looks like a phone-scuba-diving thiny. 

## 2023-11-13

Cried a bit in the toilet. Am I even a designer? What a beginning to the week.

[Tested](/process/2023-11-13/user-tests/) Kick-starter. Apparently, having an assistant that you need to wake up is not obvious and very confusing. Abandonned this idea. Also, need to make it OBVIOUS that you need to put an object somewhere.

Had feedback from Laure, really helped and lifted up my spirit. Why does the assistant have to draw the outline for you if it can just project it. Genius. Can also have several options, like outline, decompose, magic (to add more stuff) and random (to randomize the output and some spice). Feeling much better. Maybe I am a designer.

## 2023-11-12

**Pitch (what, who, where, and how), first version.**

Kick-starter is an assistant that helps people start drawing using the outlines of small objects around them. It is designed for people looking to occupy their free time. These people are open to drawing but do not know where or how to start. Kick-starter can be used at home, in the office or even at school. Simply place it on a sheet of paper and choose a small object to use as the basis for your future drawing. After analysing your object, Kick-starter draws its outline, which you can then use to kick-start your drawing.

**User journey**

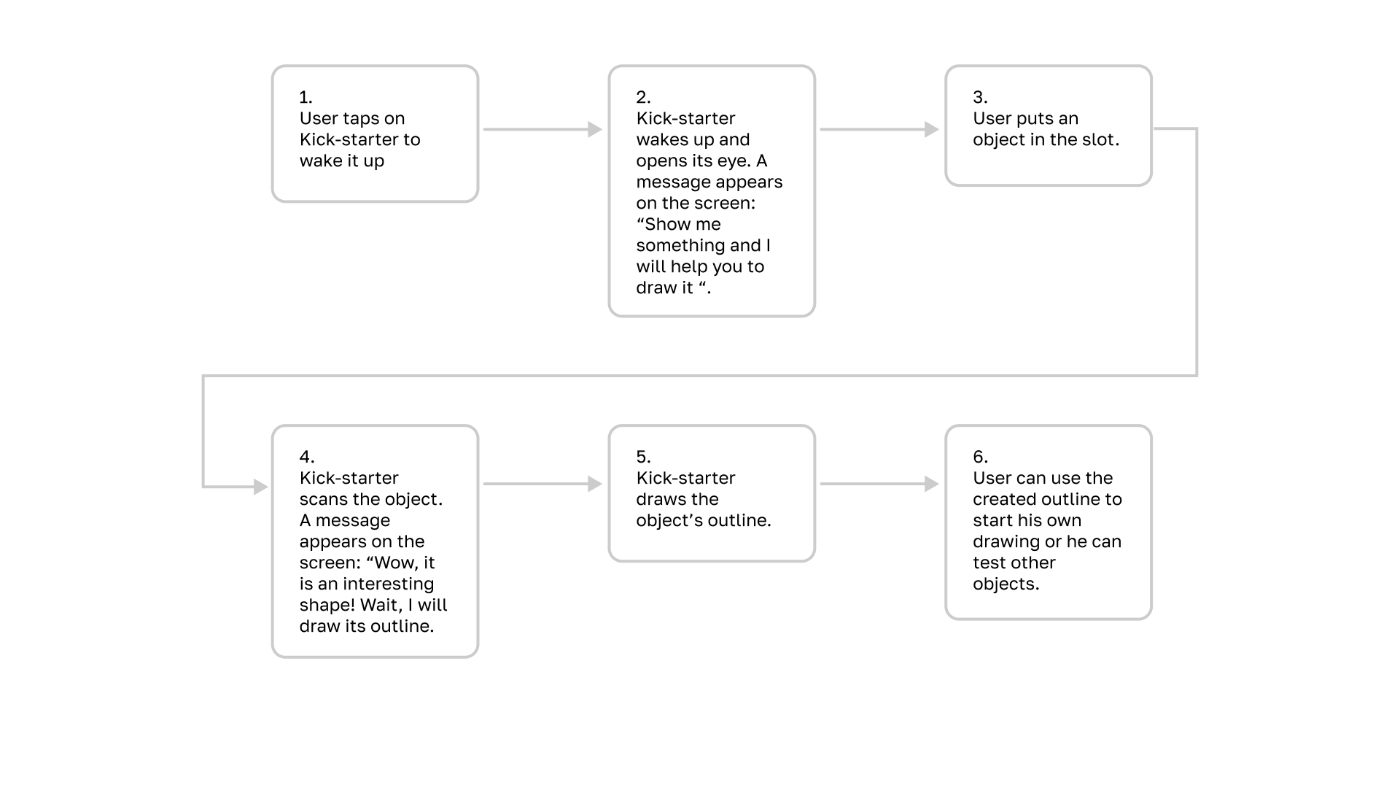
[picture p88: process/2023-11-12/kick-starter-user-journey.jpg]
kick-starter-user-journey


**Key insights**
1. There is existential boredom, when people have suddenly a lot of free time and they are looking for ways to occupy themselves.
2. A lot of people do not mind drawing but they do not know what to draw and how to start.
3. Some people feel bored when they are alone. Drawing in a collaboration can be more fun.

**Next steps**

## 2023-11-11

Made a paper prototype of [Kick-starter](/process/2023-11-11/kick-starter) - an assistant that allows you to draw the outlines of small objects and thus start a drawing.

kick-starter-1

## 2023-11-07

Prototype idea: the assistant detects if you put something on the paper, it then immediately rushes to the object and starts drawing around it. Drawing with negative space.

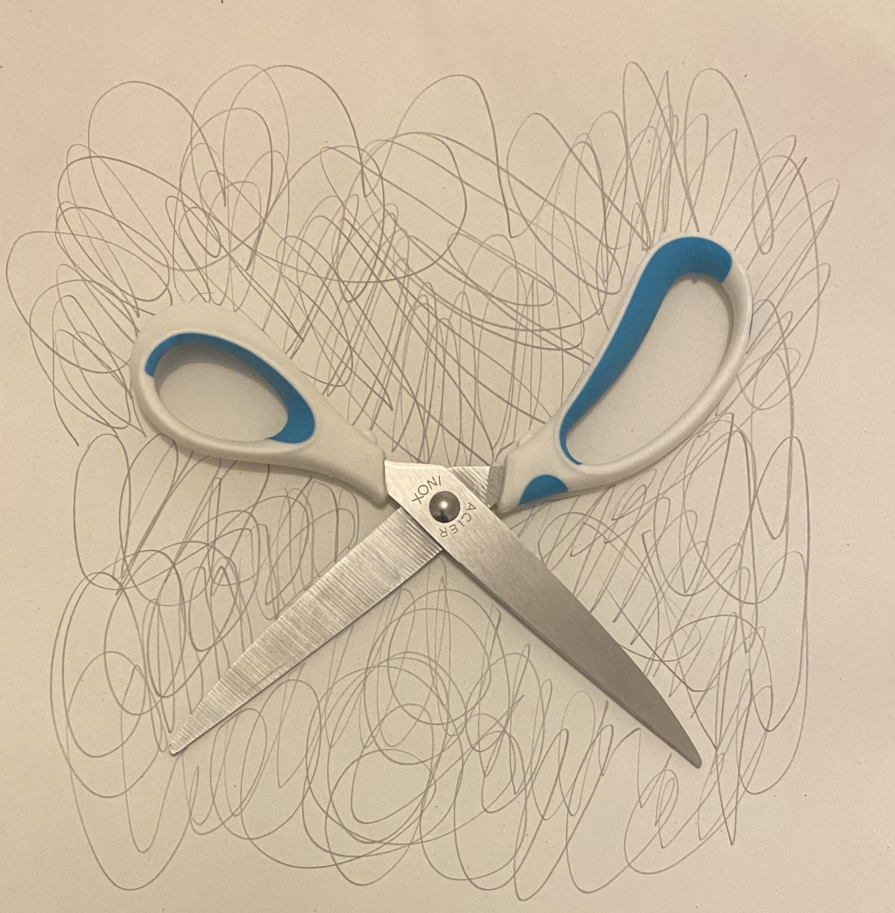
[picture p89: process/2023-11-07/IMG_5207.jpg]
negative_space_1
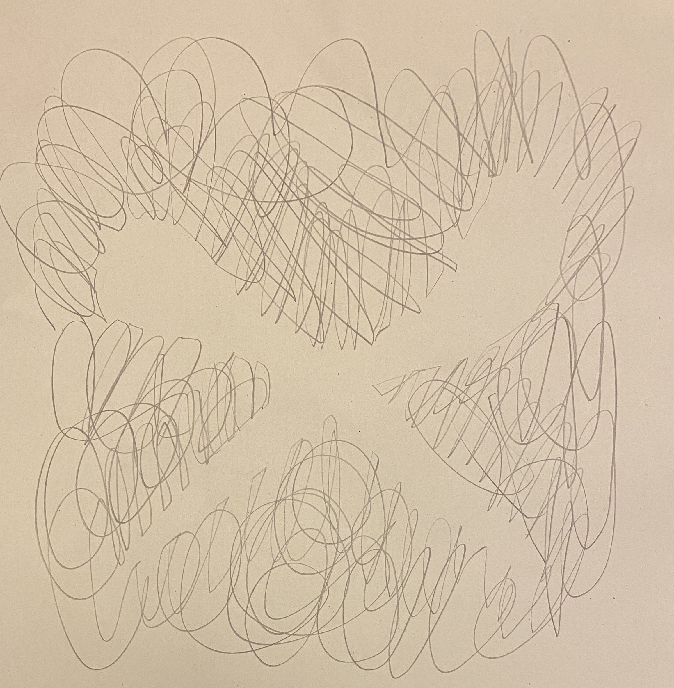
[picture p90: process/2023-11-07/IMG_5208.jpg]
negative_space_2
  

## 2023-11-03

Why do I focus on textures? My assistant could help to draw whatever you want. You put something inside it, choose what outcome you want (complexity) and it scans the object and then draws it based on your settings. Thus it invites you to explore the world around you and helps you to overcome the initial creative block ("I do not mind drawing but I do not know what to draw and how").

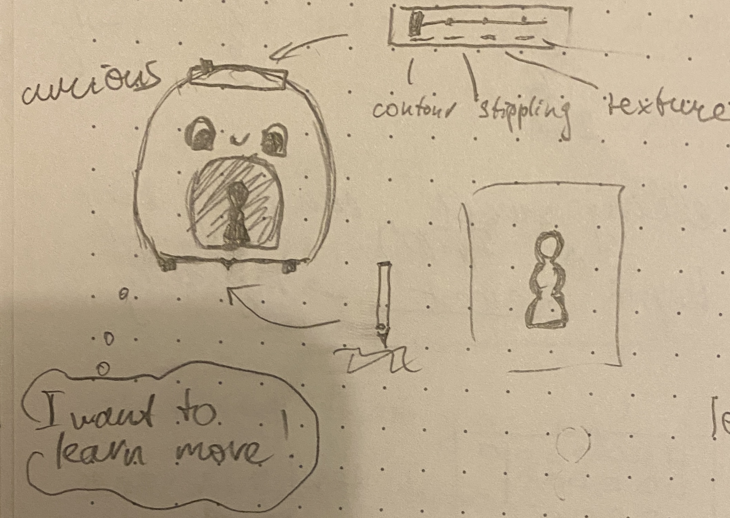
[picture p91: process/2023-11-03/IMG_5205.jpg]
prototype_3


It can say: "Show me the world and I will show you how to draw it", "I want to learn more!.

## 2023-11-01

Continued doing [texture](/process/2023-11-01/textures-new-tests) and [sound](/process/2023-11-01/sound-tests) tests. Decided not to persue with [tastes](/process/2023-11-01/taste-tests) and sounds.

Made two prototypes: [texture-to-brush hand](/process/2023-11-01/texture-to-brush-hand) texture-to-brush hand and [texture-to-image convertor](/process/2023-11-01/texture-to-image-convertor).

texture-to-image convertor

Need to think on how to add the mystery/exploration aspect to the assistant.

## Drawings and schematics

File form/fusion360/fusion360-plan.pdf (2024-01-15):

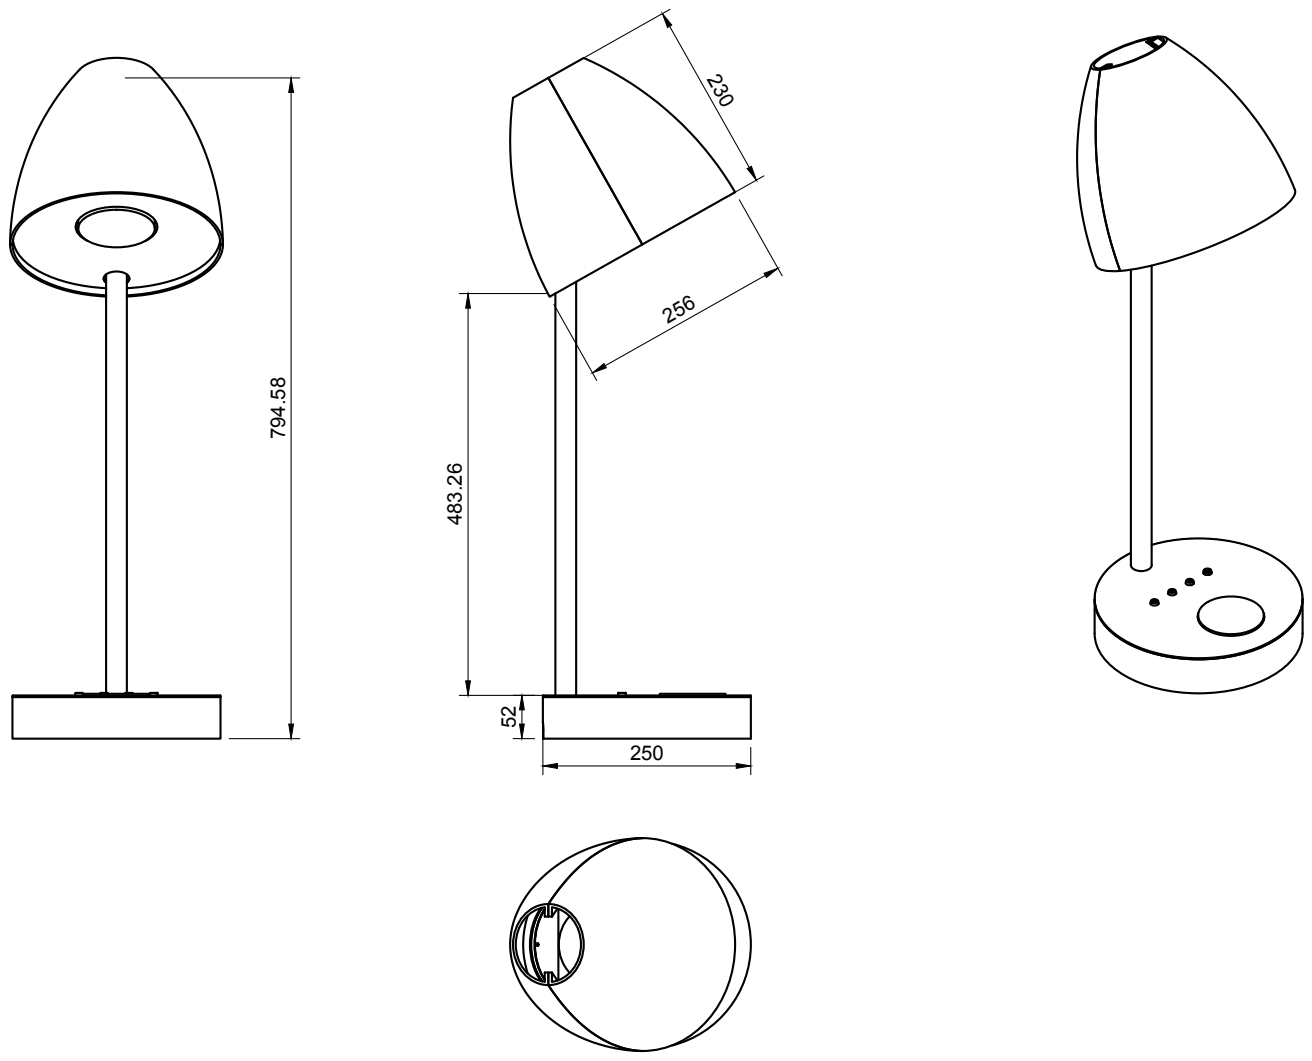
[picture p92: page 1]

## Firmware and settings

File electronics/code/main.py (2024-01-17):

from PIL import Image, ImageTk
from tkinter import Tk, Frame, Label, Canvas
from time import sleep
import RPi.GPIO as GPIO
from mfrc522 import SimpleMFRC522

GPIO.setmode(GPIO.BCM)

GPIO.setup(19, GPIO.IN, pull_up_down=GPIO.PUD_UP)
GPIO.setup(13, GPIO.IN, pull_up_down=GPIO.PUD_UP)

last_outline_state = True
last_shading_state = True

reader = SimpleMFRC522()

A4_WIDTH = 595
A4_HEIGHT = 842


root = Tk()
root.configure(background='black')
root.attributes('-fullscreen', True)
root.geometry(f"{A4_WIDTH}x{A4_HEIGHT}")
root.title("Image Projector")

canvas = Canvas(root, width=500, height=100, bd=0, bg='black', highlightthickness=0)
canvas.pack()

blank_image_file = "/home/pi/pi-rfid/images/default.jpg"


#Dictionary for each animal
bear = {
    "outline": "/home/pi/pi-rfid/images/outlines/outline-bear.jpg",
    "shading": "/home/pi/pi-rfid/images/shading/shading-bear.jpg"
}

frog = {
    "outline": "/home/pi/pi-rfid/images/outlines/outline-frog.jpg",
    "shading": "/home/pi/pi-rfid/images/shading/shading-frog.jpg"
}

plane = {
    "outline": "/home/pi/pi-rfid/images/outlines/outline-plane.jpg",
    "shading": "/home/pi/pi-rfid/images/shading/shading-plane.jpg"
}

previous_tag= ""
state = ""
button_state = ""

def read_nfc():
    try:
        tag_id, tag_text = reader.read_no_block()
        if tag_text is not None:
            print(tag_text)
            #previous_tag = tag_text
            return tag_text.strip()
        
    except:
        print("Error reading NFC tag")
        pass

def check_switch():
    global last_outline_state
    global last_shading_state
	
    input_outline_state = GPIO.input(19)
	
    if input_outline_state == False and last_outline_state == True:
        print('Outline Button Pressed')
        last_outline_state = False
        return("o_on")

    if input_outline_state == True and last_outline_state == False:
        print('Outline Button Released')
        last_outline_state = True
        return("o_off")
		
    input_shading_state = GPIO.input(13)
	
    if input_shading_state == False and last_shading_state == True:
        print('Shading Button Pressed')
        last_shading_state = False
        return("s_on")
		
    if input_shading_state == True and last_shading_state == False:
        print('Shading Button Released')
        last_shading_state = True
        return("s_off")


def display_image(image_file):
    image = Image.open(image_file)
    image = image.resize((A4_WIDTH, A4_HEIGHT), resample=Image.BICUBIC)
    tk_image = ImageTk.PhotoImage(image)
    label.config(image=tk_image)
    label.image = tk_image

def update_image():
    try:
        global state
        global previous_tag
        global button_state

        tag = read_nfc()

        button = check_switch()
        if button != None:
            button_state = button


        if tag is not None:
            if tag != previous_tag:

                if tag == "bear":
                    state = "bear"
                    button_state = "o_on"

                elif tag == "frog":
                    state = "frog"
                    button_state = "o_on"

                elif tag == "plane":
                    state = "plane"
                    button_state = "o_on"               
                
                previous_tag = tag

        if state == "bear":
            if button_state == "s_off":
                image_file = bear["shading"]
            else:
                image_file = bear["outline"]

        if state == "frog":
            if button_state == "s_off":
                image_file = frog["shading"]
            else:
                image_file = frog["outline"]

        if state == "plane":
            if button_state == "s_off":
                image_file = plane["shading"]
            else:
                image_file = plane["outline"]

        display_image(image_file)

    except:
        pass
    
    try:
        root.after(10, update_image)
    except KeyboardInterrupt:
        GPIO.cleanup() 
        exit()



label = Label(root)
label.pack()

display_image(blank_image_file)
root.after(100, update_image)

root.mainloop()

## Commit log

2023-11-01 added description to a prototype
2023-11-01 added texture to drawing prototype
2023-11-12 added prototype description
2023-11-12 added pitch
2023-11-16 added more user tests materials
2023-12-20 added form
    [snailed_it v16.f3d]
2023-12-24 added photos of head structure and new fusion file
    [snailed_it v20.f3d]
2023-12-24 renamed folders in form
    [snailed_it v20.f3d]
2024-01-04 added stl files for 4 other input objects
    [Penguin_t.stl, Plane_t.stl]
2024-01-13 updated form, added process, added final presentation v1
    [2.stl, 3.stl, 4.stl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]
2024-01-15 new buttons
    [buttom3-2.stl, buttom3-3.stl, button1-3.stl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]
2024-01-17 added fritzing file and updated devlog
    [snailed-it.fzz]
2024-01-17 updated form folder, added final fusion 360
    [2.stl, 3.stl, 4.stl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]
